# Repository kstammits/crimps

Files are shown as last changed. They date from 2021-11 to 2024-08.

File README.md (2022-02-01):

# crimps
 Mutated Kinks = Karltron Crimps

Originally cloning Mutable Instruments' Kinks
https://github.com/pichenettes/eurorack
Transferring from EAGLE to KiCad and updating from 0402 to 0805 construction means basically the whole thing is rewritten from scratch. The PCB is therefore unrelated to Kinks: Crimps is a karltron design 2021. 

Info on karltron.com/crimps

it's cc-by-sa so copyleft

On the internet forums, someone else has mentioned started a THT version, asking about it but not shared yet because reasons. 
https://modwiggler.com/forum/viewtopic.php?p=3644155

signal diode:
FDLL4148 is D1206

changing pinout on transistors, to SOT-23. so DO BE CAREFUL AND RECHECK THE PINOUT  (note v101 has the transistors on upside down, v122 is fixed)

layout looking fine in 0805

The S&H calls for a fancy C0G capacitor and OPA4171 opamp. We'll try it with a plain capacitor and TL074, which are compatible, but expect poor performance. I'm curious how poor, if it's acceptable we can save $$. Will try both, and report back here. But v101 is otherwise broken so 

when the input looks like noise at >9vpp, which is normal, the trigger goes off for successivly lower notes. feels like an accumulating towards -7.5Volts. Input values lower than -7V till self trigger If something softer is in the input, or values <7 volts absolute it will not self-trigger.  i think i need to add a capacitor somewhere or redo the ground plane.  Anytime the input sinks below -7V it pulls on the gate. Not sure it's really triggering, would need a two-channel scope to see if they coincide.  

if you keep the input above -7V, then the vgs doesn't trigger and everything is good. So I should just reduce the noise volume, the original kinks was showing just about +/-5V, and 10vpp is enough noise. mine's doing like 19vpp noise, and catching a very brief acquisition during noise spikes under -7V. 

so actually it works fine. i should/need/to/ reduce the noise volume to 10vpp to avoid the -7V issue. That's fixed by changing R27 from a 1.5M as originally given to a 1M. Now the noise is only +/-6V and everything works. then of course flip the transistors right-side-up. I've tested with only a J112 THT jfet tacked on crooked.  

Testing another JFET as replacement; the MMBFJ201 (marked 6P) is not great. Sort of works, sort of doesnt. The trigger time is not sufficient for acquisition, so each trigger can only move the sample by a few volts, and swinging +/-10V will need 2,3,4,5 triggers. Also, when the input is quite low the sample drains without triggers, so the J201 seems to have some leakage Igs as well as a higher Rds-on vs the J112. The incomplete-acquisitions problem might be okay for your use, but it really reduces the output range when the internal noise source is +/-6V and each trigger seems to only change the value to +/-1V. 

Testing the MMBF4392 (marked 6K)
Holds nicely down to -7.5V then drops, as others do, because my gate off voltage is -11, so less than four difference causes a sampling.   Seems to be working well. 

Testing the MMBFJ112 (marked 6R) last since a THT J112 was working well. Also seems to perform adequately. 
 
During hold testing, discovered unplugging and replugging the output causes a drop in the sample; perhaps this is caused by the brief short to ground pulling on the opamp. Additional decoupling caps did not help, looks like the OPA4171 final out buffer loses some state through the 180R output. Another output stage might be required to separate the held voltage from the output buffer. That's not fixable without additional chips.

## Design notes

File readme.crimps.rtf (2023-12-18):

Mutable Kinks
Karltron Crimps
21Nov08

it's cc-by-sa so copyleft
someone else started a tht version, asking about it but not shared yet because reasons.
on easyeda he doesnt know how to share that.

seems to fit in 0805 on one extra board. with no output LEDs.

FDLL4148 is D1206
i dont know if these diodes are pointing the right direction after changing footprints.
check the eagle schematic again for polarity.

21nov15

changing pinout on transistors, to SOT-23. so DO BE CAREFUL AND RECHECK THE PINOUT
checked. check.
layout looking fine in 0805. could do THT except for ICs.... well idk.
0805 is laid out now. needs review before ordering.
needs a https://www.digikey.com/en/products/detail/kemet/C0805C103J5GEC7210/8645966

the j112 seems to work well. but noise is dead.
give it an in and the s&h works. with J112 and OPA4174

FDLL pads could be taller please.
wrong jfet is fine. get a few to try.
upside down mmbf3904. needs rewrite of board.

seems the input normalled to noise is triggering the trigger perhaps by crosstalk. the falling tone is just the likelihood of a trigger getting seen.
after some exploration:
but its not crosstalk, i think its power rail fluctuations or ground plane shenanigans with the trigger's threshold, or trigger pulldown.
the original had a ton mroe decoupling, so that's a clue.

figured it out was just the gate threshold at -11 being too close to the input at -7v. we open the signal path
so really the module is fine lolol.
then changed the opa41 to a tl074 and found it pushes only -7v, so really triggery easier. the noise went up to +/-7 and that hits the gate easyyy.

v122 works great

update R27 down from 470K to maybe 330K or half 470 (parallel = 235K)

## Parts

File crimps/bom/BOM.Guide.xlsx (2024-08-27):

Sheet: BOM
Source: | /Users/karl/Workspace/KiCad/Crimps/crimps/k2.sch
Date: | Thursday, November 18, 2021 at 08:59:49 PM
Tool: | Eeschema (5.1.10-1-10_14)
Generator: | /private/var/folders/6g/062y2qc95n76y3fy2wkwz5l40000gn/T/AppTranslocation/AF1E8601-DF93-40C0-9ED7-950A2D177542/d/kicad.app/Contents/SharedSupport/plugins/bom_csv_grouped_by_value.py
Component Count: | 81
Individual Components:
Item | Qty | Reference(s) | Value | LibPart | Footprint | Datasheet
 |  | C1 | 22u | k2-eagle-import:C-USC0805 | Capacitor_THT:CP_Radial_D6.3mm_P2.50mm
 |  | C2 | 22u | k2-eagle-import:C-USC0805 | Capacitor_THT:CP_Radial_D6.3mm_P2.50mm
 |  | C3 | 100p | device:C | Capacitor_SMD:C_0805_2012Metric_Pad1.18x1.45mm_HandSolder
 |  | C4 | 100n | k2-eagle-import:C-USC0402 | Capacitor_SMD:C_0805_2012Metric_Pad1.18x1.45mm_HandSolder
 |  | C5 | 100n | k2-eagle-import:C-USC0402 | Capacitor_SMD:C_0805_2012Metric_Pad1.18x1.45mm_HandSolder
 |  | C6 | 100n | k2-eagle-import:C-USC0805 | Capacitor_SMD:C_0805_2012Metric_Pad1.18x1.45mm_HandSolder
 |  | C7 | 100n | k2-eagle-import:C-USC0805 | Capacitor_SMD:C_0805_2012Metric_Pad1.18x1.45mm_HandSolder
 |  | C8 | 100n | k2-eagle-import:C-USC0402 | Capacitor_SMD:C_0805_2012Metric_Pad1.18x1.45mm_HandSolder
 |  | C9 | 100n | k2-eagle-import:C-USC0402 | Capacitor_SMD:C_0805_2012Metric_Pad1.18x1.45mm_HandSolder
 |  | C10 | 4.7u | k2-eagle-import:C-USC0603 | Capacitor_SMD:C_0805_2012Metric_Pad1.18x1.45mm_HandSolder
 |  | C11 | 100n | device:C | Capacitor_SMD:C_0805_2012Metric_Pad1.18x1.45mm_HandSolder
 |  | C12 | 10n | device:C | Capacitor_SMD:C_0805_2012Metric_Pad1.18x1.45mm_HandSolder
 |  | D1 | S1JL | Device:D | Diode_THT:D_DO-41_SOD81_P10.16mm_Horizontal
 |  | D2 | S1JL | Device:D | Diode_THT:D_DO-41_SOD81_P10.16mm_Horizontal
 |  | D3 | 1N4148 | device:D | Diode_SMD:D_1206_3216Metric_Pad1.42x1.75mm_HandSolder
 |  | D4 | 1N4148 | device:D | Diode_SMD:D_1206_3216Metric_Pad1.42x1.75mm_HandSolder
 |  | D5 | 1N4148 | device:D | Diode_SMD:D_1206_3216Metric_Pad1.42x1.75mm_HandSolder
 |  | D6 | 1N4148 | device:D | Diode_SMD:D_1206_3216Metric_Pad1.42x1.75mm_HandSolder
 |  | D7 | 1N4148 | device:D | Diode_SMD:D_1206_3216Metric_Pad1.42x1.75mm_HandSolder
 |  | D8 | 1N4148 | device:D | Diode_SMD:D_1206_3216Metric_Pad1.42x1.75mm_HandSolder
 |  | D9 | 1N4148 | device:D | Diode_SMD:D_1206_3216Metric_Pad1.42x1.75mm_HandSolder
 |  | D10 | 1N4148 | device:D | Diode_SMD:D_1206_3216Metric_Pad1.42x1.75mm_HandSolder
 |  | D11 | 1N4148 | device:D | Diode_SMD:D_1206_3216Metric_Pad1.42x1.75mm_HandSolder
 |  | D12 | 1N4148 | device:D | Diode_SMD:D_1206_3216Metric_Pad1.42x1.75mm_HandSolder
 |  | IC1 | TL074 | Amplifier_Operational:TL074 | Package_SO:SOIC-14_3.9x8.7mm_P1.27mm
 |  | IC2 | TL072 | Amplifier_Operational:TL072 | Package_SO:SOIC-8_3.9x4.9mm_P1.27mm
 |  | IC3 | TL074 | Amplifier_Operational:TL074 | Package_SO:SOIC-14_3.9x8.7mm_P1.27mm
 |  | J1 | PJ301_THONKICONN6 | k2-eagle-import:PJ301_THONKICONN6 | k2:WQP_PJ_301M6
 |  | J2 | PJ301_THONKICONN6 | k2-eagle-import:PJ301_THONKICONN6 | k2:WQP_PJ_301M6
 |  | J3 | PJ301_THONKICONN6 | k2-eagle-import:PJ301_THONKICONN6 | k2:WQP_PJ_301M6
 |  | J4 | PJ301_THONKICONN6 | k2-eagle-import:PJ301_THONKICONN6 | k2:WQP_PJ_301M6
 |  | J5 | PJ301_THONKICONN6 | k2-eagle-import:PJ301_THONKICONN6 | k2:WQP_PJ_301M6
 |  | J6 | PJ301_THONKICONN6 | k2-eagle-import:PJ301_THONKICONN6 | k2:WQP_PJ_301M6
 |  | J7 | PJ301_THONKICONN6 | k2-eagle-import:PJ301_THONKICONN6 | k2:WQP_PJ_301M6
 |  | J8 | PJ301_THONKICONN6 | k2-eagle-import:PJ301_THONKICONN6 | k2:WQP_PJ_301M6
 |  | J9 | PJ301_THONKICONN6 | k2-eagle-import:PJ301_THONKICONN6 | k2:WQP_PJ_301M6
 |  | J10 | PJ301_THONKICONN6 | k2-eagle-import:PJ301_THONKICONN6 | k2:WQP_PJ_301M6
 |  | J11 | PJ301_THONKICONN6 | k2-eagle-import:PJ301_THONKICONN6 | k2:WQP_PJ_301M6
 |  | J12 | PJ301_THONKICONN6 | k2-eagle-import:PJ301_THONKICONN6 | k2:WQP_PJ_301M6
 |  | J13 | Conn_01x05_Female | Connector:Conn_01x05_Female | Connector_PinHeader_2.54mm:PinHeader_1x05_P2.54mm_Vertical | ~
 |  | J14 | Conn_01x05_Female | Connector:Conn_01x05_Female | Connector_PinHeader_2.54mm:PinHeader_1x05_P2.54mm_Vertical | ~
 |  | J15 | Conn_01x05_Female | Connector:Conn_01x05_Female | Connector_PinHeader_2.54mm:PinHeader_1x05_P2.54mm_Vertical | ~
 |  | J16 | Conn_01x05_Male | Connector:Conn_01x05_Male | Connector_PinHeader_2.54mm:PinHeader_1x05_P2.54mm_Vertical | ~
 |  | J17 | Conn_01x05_Male | Connector:Conn_01x05_Male | Connector_PinHeader_2.54mm:PinHeader_1x05_P2.54mm_Vertical | ~
 |  | J18 | Conn_01x05_Male | Connector:Conn_01x05_Male | Connector_PinHeader_2.54mm:PinHeader_1x05_P2.54mm_Vertical | ~
 |  | JP1 | M05X2PTH | k2-eagle-import:M05X2PTH | k2:AVR_ICSP
 |  | Q1 | MMBFJ309 | device:Q_NJFET_SDG | Package_TO_SOT_SMD:SOT-23_Handsoldering
 |  | Q2 | MMBT3904 | device:Q_NPN_EBC | Package_TO_SOT_SMD:SOT-23_Handsoldering
 |  | Q3 | MMBT3904 | device:Q_NPN_EBC | Package_TO_SOT_SMD:SOT-23_Handsoldering
 |  | R1 | 180 | k2-eagle-import:R-US_R0402 | Resistor_SMD:R_0805_2012Metric_Pad1.20x1.40mm_HandSolder
 |  | R2 | 180 | k2-eagle-import:R-US_R0402 | Resistor_SMD:R_0805_2012Metric_Pad1.20x1.40mm_HandSolder
 |  | R3 | 180 | k2-eagle-import:R-US_R0402 | Resistor_SMD:R_0805_2012Metric_Pad1.20x1.40mm_HandSolder
 |  | R4 | 180 | k2-eagle-import:R-US_R0402 | Resistor_SMD:R_0805_2012Metric_Pad1.20x1.40mm_HandSolder
 |  | R5 | 180 | k2-eagle-import:R-US_R0402 | Resistor_SMD:R_0805_2012Metric_Pad1.20x1.40mm_HandSolder
 |  | R6 | 180 | k2-eagle-import:R-US_R0402 | Resistor_SMD:R_0805_2012Metric_Pad1.20x1.40mm_HandSolder
 |  | R7 | 100k | k2-eagle-import:R-US_R0402 | Resistor_SMD:R_0805_2012Metric_Pad1.20x1.40mm_HandSolder
 |  | R8 | 180 | k2-eagle-import:R-US_R0402 | Resistor_SMD:R_0805_2012Metric_Pad1.20x1.40mm_HandSolder
 |  | R9 | 200k | k2-eagle-import:R-US_R0402 | Resistor_SMD:R_0805_2012Metric_Pad1.20x1.40mm_HandSolder
 |  | R10 | 200k | k2-eagle-import:R-US_R0402 | Resistor_SMD:R_0805_2012Metric_Pad1.20x1.40mm_HandSolder
 |  | R11 | 200k | k2-eagle-import:R-US_R0402 | Resistor_SMD:R_0805_2012Metric_Pad1.20x1.40mm_HandSolder
 |  | R12 | 200k | k2-eagle-import:R-US_R0402 | Resistor_SMD:R_0805_2012Metric_Pad1.20x1.40mm_HandSolder
 |  | R13 | 200k | k2-eagle-import:R-US_R0402 | Resistor_SMD:R_0805_2012Metric_Pad1.20x1.40mm_HandSolder
 |  | R14 | 100k | k2-eagle-import:R-US_R0402 | Resistor_SMD:R_0805_2012Metric_Pad1.20x1.40mm_HandSolder
 |  | R15 | 200k | k2-eagle-import:R-US_R0402 | Resistor_SMD:R_0805_2012Metric_Pad1.20x1.40mm_HandSolder
 |  | R16 | 100k | k2-eagle-import:R-US_R0402 | Resistor_SMD:R_0805_2012Metric_Pad1.20x1.40mm_HandSolder
 |  | R17 | 100k | k2-eagle-import:R-US_R0402 | Resistor_SMD:R_0805_2012Metric_Pad1.20x1.40mm_HandSolder
 |  | R18 | 100k | k2-eagle-import:R-US_R0402 | Resistor_SMD:R_0805_2012Metric_Pad1.20x1.40mm_HandSolder
 |  | R19 | 220k | k2-eagle-import:R-US_R0402 | Resistor_SMD:R_0805_2012Metric_Pad1.20x1.40mm_HandSolder
 |  | R20 | 220k | k2-eagle-import:R-US_R0402 | Resistor_SMD:R_0805_2012Metric_Pad1.20x1.40mm_HandSolder
 |  | R21 | 220k | k2-eagle-import:R-US_R0402 | Resistor_SMD:R_0805_2012Metric_Pad1.20x1.40mm_HandSolder
 |  | R22 | 220k | k2-eagle-import:R-US_R0402 | Resistor_SMD:R_0805_2012Metric_Pad1.20x1.40mm_HandSolder
 |  | R23 | 10k | k2-eagle-import:R-US_R0402 | Resistor_SMD:R_0805_2012Metric_Pad1.20x1.40mm_HandSolder
 |  | R24 | 1.0M | k2-eagle-import:R-US_R0402 | Resistor_SMD:R_0805_2012Metric_Pad1.20x1.40mm_HandSolder
 |  | R25 | 10k | k2-eagle-import:R-US_R0402 | Resistor_SMD:R_0805_2012Metric_Pad1.20x1.40mm_HandSolder
 |  | R26 | 1.0M | k2-eagle-import:R-US_R0402 | Resistor_SMD:R_0805_2012Metric_Pad1.20x1.40mm_HandSolder
 |  | R27 | 1.5M | k2-eagle-import:R-US_R0402 | Resistor_SMD:R_0805_2012Metric_Pad1.20x1.40mm_HandSolder
 |  | R28 | 100k | k2-eagle-import:R-US_R0402 | Resistor_SMD:R_0805_2012Metric_Pad1.20x1.40mm_HandSolder
 |  | R29 | 1.0M | k2-eagle-import:R-US_R0402 | Resistor_SMD:R_0805_2012Metric_Pad1.20x1.40mm_HandSolder
 |  | R30 | 470k | k2-eagle-import:R-US_R0402 | Resistor_SMD:R_0805_2012Metric_Pad1.20x1.40mm_HandSolder
 |  | R31 | 4.7k | k2-eagle-import:R-US_R0402 | Resistor_SMD:R_0805_2012Metric_Pad1.20x1.40mm_HandSolder
 |  | R32 | 100k | k2-eagle-import:R-US_R0402 | Resistor_SMD:R_0805_2012Metric_Pad1.20x1.40mm_HandSolder
Collated Components:
Item | Qty | Reference(s) | Value | LibPart | Footprint | Datasheet
1 | 2 | C1, C2 | 22u | k2-eagle-import:C-USC0805 | Capacitor_THT:CP_Radial_D6.3mm_P2.50mm
2 | 1 | C3 | 100p | device:C | Capacitor_SMD:C_0805_2012Metric_Pad1.18x1.45mm_HandSolder
3 | 4 | C4, C5, C8, C9 | 100n | k2-eagle-import:C-USC0402 | Capacitor_SMD:C_0805_2012Metric_Pad1.18x1.45mm_HandSolder
4 | 2 | C6, C7 | 100n | k2-eagle-import:C-USC0805 | Capacitor_SMD:C_0805_2012Metric_Pad1.18x1.45mm_HandSolder
5 | 1 | C10 | 4.7u | k2-eagle-import:C-USC0603 | Capacitor_SMD:C_0805_2012Metric_Pad1.18x1.45mm_HandSolder
6 | 1 | C11 | 100n | device:C | Capacitor_SMD:C_0805_2012Metric_Pad1.18x1.45mm_HandSolder
7 | 1 | C12 | 10n | device:C | Capacitor_SMD:C_0805_2012Metric_Pad1.18x1.45mm_HandSolder
8 | 2 | D1, D2 | S1JL | Device:D | Diode_THT:D_DO-41_SOD81_P10.16mm_Horizontal
9 | 10 | D3, D4, D5, D6, D7, D8, D9, D10, D11, D12 | 1N4148 | device:D | Diode_SMD:D_1206_3216Metric_Pad1.42x1.75mm_HandSolder
10 | 2 | IC1, IC3 | TL074 | Amplifier_Operational:TL074 | Package_SO:SOIC-14_3.9x8.7mm_P1.27mm
11 | 1 | IC2 | TL072 | Amplifier_Operational:TL072 | Package_SO:SOIC-8_3.9x4.9mm_P1.27mm
12 | 12 | J1, J2, J3, J4, J5, J6, J7, J8, J9, J10, J11, J12 | PJ301_THONKICONN6 | k2-eagle-import:PJ301_THONKICONN6 | k2:WQP_PJ_301M6
13 | 3 | J13, J14, J15 | Conn_01x05_Female | Connector:Conn_01x05_Female | Connector_PinHeader_2.54mm:PinHeader_1x05_P2.54mm_Vertical | ~
14 | 3 | J16, J17, J18 | Conn_01x05_Male | Connector:Conn_01x05_Male | Connector_PinHeader_2.54mm:PinHeader_1x05_P2.54mm_Vertical | ~
15 | 1 | JP1 | M05X2PTH | k2-eagle-import:M05X2PTH | k2:AVR_ICSP
16 | 1 | Q1 | MMBFJ309 | device:Q_NJFET_SDG | Package_TO_SOT_SMD:SOT-23_Handsoldering
17 | 2 | Q2, Q3 | MMBT3904 | device:Q_NPN_EBC | Package_TO_SOT_SMD:SOT-23_Handsoldering
18 | 7 | R1, R2, R3, R4, R5, R6, R8 | 180 | k2-eagle-import:R-US_R0402 | Resistor_SMD:R_0805_2012Metric_Pad1.20x1.40mm_HandSolder
19 | 7 | R7, R14, R16, R17, R18, R28, R32 | 100k | k2-eagle-import:R-US_R0402 | Resistor_SMD:R_0805_2012Metric_Pad1.20x1.40mm_HandSolder
20 | 6 | R9, R10, R11, R12, R13, R15 | 200k | k2-eagle-import:R-US_R0402 | Resistor_SMD:R_0805_2012Metric_Pad1.20x1.40mm_HandSolder
21 | 4 | R19, R20, R21, R22 | 220k | k2-eagle-import:R-US_R0402 | Resistor_SMD:R_0805_2012Metric_Pad1.20x1.40mm_HandSolder
22 | 2 | R23, R25 | 10k | k2-eagle-import:R-US_R0402 | Resistor_SMD:R_0805_2012Metric_Pad1.20x1.40mm_HandSolder
23 | 3 | R24, R26, R29 | 1.0M | k2-eagle-import:R-US_R0402 | Resistor_SMD:R_0805_2012Metric_Pad1.20x1.40mm_HandSolder
24 | 1 | R27 | 1.5M | k2-eagle-import:R-US_R0402 | Resistor_SMD:R_0805_2012Metric_Pad1.20x1.40mm_HandSolder
25 | 1 | R30 | 470k | k2-eagle-import:R-US_R0402 | Resistor_SMD:R_0805_2012Metric_Pad1.20x1.40mm_HandSolder
26 | 1 | R31 | 4.7k | k2-eagle-import:R-US_R0402 | Resistor_SMD:R_0805_2012Metric_Pad1.20x1.40mm_HandSolder

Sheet: GUIDE
Crimps v122 karltron.com December 2021 - Derived from Mutable Kinks v4.1 cc-by-sa
Step | Qty | Reference(s) | Value | Footprint | Note
1 | 7 | R1, R2, R3, R4, R5, R6, R8 | 180R | 0805 plain | output protections, could be 100R to 1K
2 | 7 | R7, R14, R16, R17, R18, R28, R32 | 100k | 0805 plain
3 | 6 | R9, R10, R11, R12, R13, R15 | 200k | 0805 plain
4 | 4 | R19, R20, R21, R22 | 220k | 0805 plain
5 | 2 | R23, R25 | 10k | 0805 plain
6 | 3 | R24, R26, R29 | 1.0M | 0805 plain
7 | 2 | R27, R30 | 470k | 0805 plain | R27 sets noise volume
8 | 1 | R31 | 4.7k | 0805 plain
9 | 1 | C3 | 100p | 0805 plain | trigger conditioning
10 | 7 | C4, C5, C6, C7, C8, C9,C11 | 100n | 0805 plain
11 | 1 | C10 | 4.7u | 0805 plain | buffer before noise generator, value not critical
12 | 1 | C12 | 10n | 0805 C0G special | sample/hold
13 | 10 | D3, D4, D5, D6, D7, D8, D9, D10, D11, D12 | 1N4148 or FDLL4148 | Diode_SMD:D_1206_3216Metric_Pad1.42x1.75mm_HandSolder | FDLL4148 or generic signal diode
14 | 1 | IC3 | OPA4171 | SOIC-14_3.9x8.7mm_P1.27mm | a tl074 almost works but the fancy opamp is better
15 | 1 | IC1 | TL074 | SOIC-14_3.9x8.7mm_P1.27mm
16 | 1 | IC2 | TL072 | SOIC-8_3.9x4.9mm_P1.27mm
17 | 1 | Q1 | MMBFJ309 | SOT-23 | J112 and MMBF4392 work too
18 | 2 | Q2, Q3 | MMBT3904 | SOT-23 | NPN Plain
19 | 1 | JP1 | M05X2PTH | power connector 2x5 | shrouded fits
20 | 2 | C1, C2 | 22u | Cap_THT:D6.3mm_P2.50mm | pre-bend to lay flat on board inside
21 | 2 | D1, D2 | 1N4001 or 1N5819 | Diode_THT:D_DO-41_SOD81 | reverse power protection optional, could jumper these with wire instead of series diode drop
22 | 3 | J13, J14, J15 | Conn_01x05_Female | Connector_PinHeader_2.54mm:PinHeader_1x05_P2.54mm_Vertical
23 | 3 | J16, J17, J18 | Conn_01x05_Male | Connector_PinHeader_2.54mm:PinHeader_1x05_P2.54mm_Vertical
24 | 12 | J1, J2, J3, J4, J5, J6, J7, J8, J9, J10, J11, J12 | PJ301 THONKICONN | Switching Mono-Jack

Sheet: Costing
Step | Qty | Reference(s) | Value | Footprint | Note | Shopping | Cost Estimate | Extended
1 | 7 | R1, R2, R3, R4, R5, R6, R8 | 180R | 0805 plain |  | incoming Mouser | $0.01 | $0.07
2 | 7 | R7, R14, R16, R17, R18, R28, R32 | 100k | 0805 plain |  |  | $0.01 | $0.07 | Packing/Picking | PCB Set | Total Kit Price estimate
3 | 6 | R9, R10, R11, R12, R13, R15 | 200k | 0805 plain |  | incoming Mouser | $0.01 | $0.06 | $30.00 | $20.00 | $67.67
4 | 4 | R19, R20, R21, R22 | 220k | 0805 plain |  |  | $0.01 | $0.04
5 | 2 | R23, R25 | 10k | 0805 plain |  |  | $0.01 | $0.02
6 | 3 | R24, R26, R29 | 1.0M | 0805 plain |  |  | $0.01 | $0.03
7 | 1 | R27 | 1.5M | 0805 plain | change to 1M |  | $0.01 | $0.01
8 | 1 | R30 | 470k | 0805 plain |  |  | $0.01 | $0.01
9 | 1 | R31 | 4.7k | 0805 plain |  |  | $0.01 | $0.01
10 | 1 | C3 | 100p | 0805 plain |  | incoming Mouser | $0.04 | $0.04
11 | 6 | C4, C5, C6, C7, C8, C9,C11 | 100n | 0805 plain |  |  | $0.02 | $0.12
12 | 1 | C10 | 4.7u | 0805 plain | buffer before noise generator, value not critical |  | $0.10 | $0.10
13 | 1 | C12 | 10n | 0805 C0G special | sample/hold | incoming Mouser | $0.15 | $0.15
14 | 10 | D3, D4, D5, D6, D7, D8, D9, D10, D11, D12 | 1N4148 or FDLL4148 | Diode_SMD:D_1206_3216Metric_Pad1.42x1.75mm_HandSolder | FDLL4148 or generic signal diode |  | $0.04 | $0.40
15 | 1 | IC3 | OPA4147 or maybe TL074 IDK | Package_SO:SOIC-14_3.9x8.7mm_P1.27mm |  | incoming Mouser | $3.00 | $3.00
16 | 1 | IC1 | TL074 | Package_SO:SOIC-14_3.9x8.7mm_P1.27mm |  |  | $0.50 | $0.50
17 | 1 | IC2 | TL072 | Package_SO:SOIC-8_3.9x4.9mm_P1.27mm |  |  | $0.50 | $0.50
18 | 1 | Q1 | MMBFJ309 | SOT-23 | jfet | incoming eBay 2022 | $0.30 | $0.30
19 | 2 | Q2, Q3 | MMBT3904 | SOT-23 | NPN Plain |  | $0.10 | $0.20
20 | 2 | C1, C2 | 22u | Capacitor_THT:CP_Radial_D6.3mm_P2.50mm |  |  | $0.30 | $0.60
21 | 2 | D1, D2 | 1N4001 or 1N5819 | Diode_THT:D_DO-41_SOD81 | reverse power protection optional, could jumper these with wire instead of series diode drop |  | $0.20 | $0.40
22 | 3 | J13, J14, J15 | Conn_01x05_Female | Connector_PinHeader_2.54mm:PinHeader_1x05_P2.54mm_Vertical |  |  | $0.15 | $0.45
23 | 3 | J16, J17, J18 | Conn_01x05_Male | Connector_PinHeader_2.54mm:PinHeader_1x05_P2.54mm_Vertical |  |  | $0.15 | $0.45
24 | 1 | JP1 | M05X2PTH | power connector 2x5 | shrouded should fit |  | $0.25 | $0.25
25 | 12 | J1, J2, J3, J4, J5, J6, J7, J8, J9, J10, J11, J12 | PJ301_THONKICONN6 | Switching Mono-Jack |  |  | $0.25 | $3.00
 | 1 | power cable |  |  |  |  | $1.00 | $1.00
 |  | PCBs

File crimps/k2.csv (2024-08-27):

Source: | /Users/karl/Workspace/KiCad/Crimps/crimps/k2.kicad_sch
Date: | 2024 August 26, Monday 20:46:26
Tool: | Eeschema 7.0.2-0
Generator: | /Applications/KiCad/KiCad.app/Contents/SharedSupport/plugins/bom_csv_grouped_by_value_with_fp.py
Component Count: | 81
Ref | Qnty | Value | Cmp name | Footprint | Description | Vendor | DNP
C1, C2 | 2 | 22u | C-USC0805 | Capacitor_THT:CP_Radial_D6.3mm_P2.50mm
C3 | 1 | 100p | C-device | Capacitor_SMD:C_0805_2012Metric_Pad1.18x1.45mm_HandSolder
C4, C5, C6, C7, C8, C9, C11 | 7 | 100n | C-device | Capacitor_SMD:C_0805_2012Metric_Pad1.18x1.45mm_HandSolder
C10 | 1 | 4.7u | C-USC0603 | Capacitor_SMD:C_0805_2012Metric_Pad1.18x1.45mm_HandSolder
C12 | 1 | 10n | C-device | Capacitor_SMD:C_0805_2012Metric_Pad1.18x1.45mm_HandSolder
D1, D2 | 2 | S1JL | D | Diode_THT:D_DO-41_SOD81_P10.16mm_Horizontal | Diode
D3, D4, D5, D6, D7, D8, D9, D10, D11, D12 | 10 | 1N4148 | D-device | Diode_SMD:D_1206_3216Metric_Pad1.42x1.75mm_HandSolder
IC1 | 1 | TL074 | TL074 | Package_SO:SOIC-14_3.9x8.7mm_P1.27mm | Quad Low-Noise JFET-Input Operational Amplifiers, DIP-14/SOIC-14
IC2 | 1 | TL072 | TL072 | Package_SO:SOIC-8_3.9x4.9mm_P1.27mm | Dual Low-Noise JFET-Input Operational Amplifiers, DIP-8/SOIC-8
IC3 | 1 | OPA4171 | TL074 | Package_SO:SOIC-14_3.9x8.7mm_P1.27mm | Quad Low-Noise JFET-Input Operational Amplifiers, DIP-14/SOIC-14
J1, J2, J3, J4, J5, J6, J7, J8, J9, J10, J11, J12 | 12 | PJ301_THONKICONN6 | PJ301_THONKICONN6 | k2:WQP_PJ_301M6
J13, J14, J15 | 3 | Conn_01x05_Female | Conn_01x05_Female-Connector | Connector_PinHeader_2.54mm:PinHeader_1x05_P2.54mm_Vertical
J16, J17, J18 | 3 | Conn_01x05_Male | Conn_01x05_Male-Connector | Connector_PinHeader_2.54mm:PinHeader_1x05_P2.54mm_Vertical
JP1 | 1 | M05X2PTH | M05X2PTH | k2:AVR_ICSP
Q1 | 1 | MMBFJ309 | Q_NJFET_SDG-device | Package_TO_SOT_SMD:SOT-23_Handsoldering
Q2, Q3 | 2 | MMBT3904 | Q_NPN_BEC-device | Package_TO_SOT_SMD:SOT-23_Handsoldering
R1, R2, R3, R4, R5, R6, R8 | 7 | 180 | R-US_R0402 | Resistor_SMD:R_0805_2012Metric_Pad1.20x1.40mm_HandSolder
R7, R14, R16, R17, R18, R28, R32 | 7 | 100k | R-US_R0402 | Resistor_SMD:R_0805_2012Metric_Pad1.20x1.40mm_HandSolder
R9, R10, R11, R12, R13, R15 | 6 | 200k | R-US_R0402 | Resistor_SMD:R_0805_2012Metric_Pad1.20x1.40mm_HandSolder
R19, R20, R21, R22 | 4 | 220k | R-US_R0402 | Resistor_SMD:R_0805_2012Metric_Pad1.20x1.40mm_HandSolder
R23, R25 | 2 | 10k | R-US_R0402 | Resistor_SMD:R_0805_2012Metric_Pad1.20x1.40mm_HandSolder
R24, R26, R29 | 3 | 1.0M | R-US_R0402 | Resistor_SMD:R_0805_2012Metric_Pad1.20x1.40mm_HandSolder
R27 | 1 | 470K | R-US_R0402 | Resistor_SMD:R_0805_2012Metric_Pad1.20x1.40mm_HandSolder
R30 | 1 | 470k | R-US_R0402 | Resistor_SMD:R_0805_2012Metric_Pad1.20x1.40mm_HandSolder
R31 | 1 | 4.7k | R-US_R0402 | Resistor_SMD:R_0805_2012Metric_Pad1.20x1.40mm_HandSolder

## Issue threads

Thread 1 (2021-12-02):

Report back on using plain capacitors and TL074

drChungus, 2021-12-02:
Heyy,

Believe it or not, I am also considering building the Kinks nowadays and had the same idea to exchange the opamp to a more generic (and currently available) alternative. I was just wondering if you could go ahead with the build with the TL074 and if it really did make a difference in the S&H performance?

Thanks!

kstammits, 2021-12-13:
I'm having other issues on this version of the board. Will test out opamps after the rest of it is working.   For sure we don't need tantalums, i'm using MLCC and it seems okay. Kept with the C0G on the hold cap, and have so far the wrong JFET.  Today's board layout has some crosstalk problem where input noise can trigger the sampling, so that's broken. needs a re-route.

kstammits, 2021-12-17:
The strange self-triggering behavior, as it turns out, is the nature of a JFET based analog S&H. The voltage between gate and source needs to be better than 3 or 4 volts to ensure it is not sampling. Initially my noise source, normalled to input, was running +/-9V and whenever it hit -7V it would initiate a sample. This is solved in the original Kinks by changing the noise source to only +/-5V. Same here, I'm adjusting R27 to 1M so we have noise at +/-6V and no more self-triggers.

 This is relevant to the opamp choice question because the TL074 cannot output within 3-4 volts of its negative rail.  therefore the trigger/not trigger state is about -7V, and your JFET will sample whenever the input gets to about -3V, which is all the darn time with good noise input.

You can workaround this problem by further reducing the internal noise source at R27 to maybe 330K, but I think that really hobbles the utility.  In this instance we want a better than average opamp so that it can well encompass the plain opamps the rest of your system is feeding it.  If your input is a not rail-to-rail opamp then it never reaches this problematic region. Maybe also good in 15V systems.

Have not tested cheaper holding capacitors, expect it to reduce the hold time (increase droop), and I don't know what hold time is acceptable for all users, so there's no harm keeping with the special ones at fifteen cents each.    https://www.mouser.com/ProductDetail/810-CGA4C2C0G1H103J

KeLaiFu, 2021-12-18:
sorry its a little vague, but I saw another version of this posted a few days ago that mentioned some additional tuning was needed for the S&H circuit. I think my tuning they meant carefully matching components.

kstammits, 2021-12-29:
The key issue with the opamp seems to be the rail-to-rail nature. the sampling/hold action triggers whenever the trigger/gate goes high. The JFET calls high anything not more than 3 or 4 volts below the inputs. You could maybe find a special JFET who thinks that threshold is 2 volts or 5 volts. But in any event, when the trigger is not being triggered, the opamp is buffering it as low as it can go. For a TL074 that might be only -8 volts, so your S&H will take a sample whenever the input gets to -4V; and with a +/-5V noise normalled to in, that's all the time, and the module is useless.  So you could tune the normal noise to just +/-2V, or use a rail-to-rail opamp, so it can reproduce -11V and withstand a -5V at the input.

In conclusion, the originally specced OPA**** works better than a cheaper opamp.

Closed 2021-12-29.

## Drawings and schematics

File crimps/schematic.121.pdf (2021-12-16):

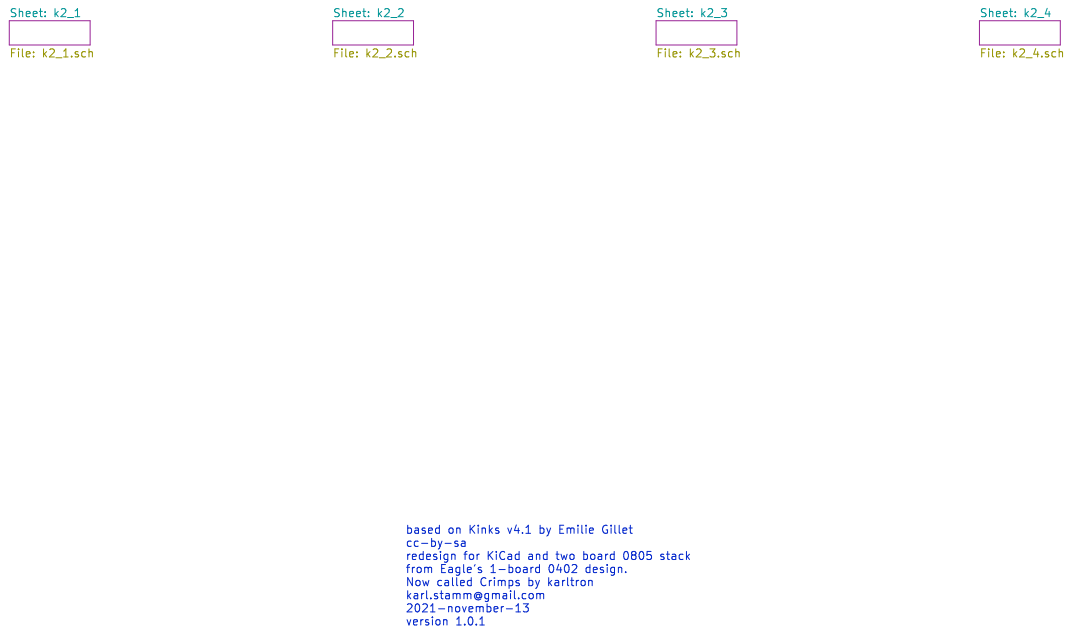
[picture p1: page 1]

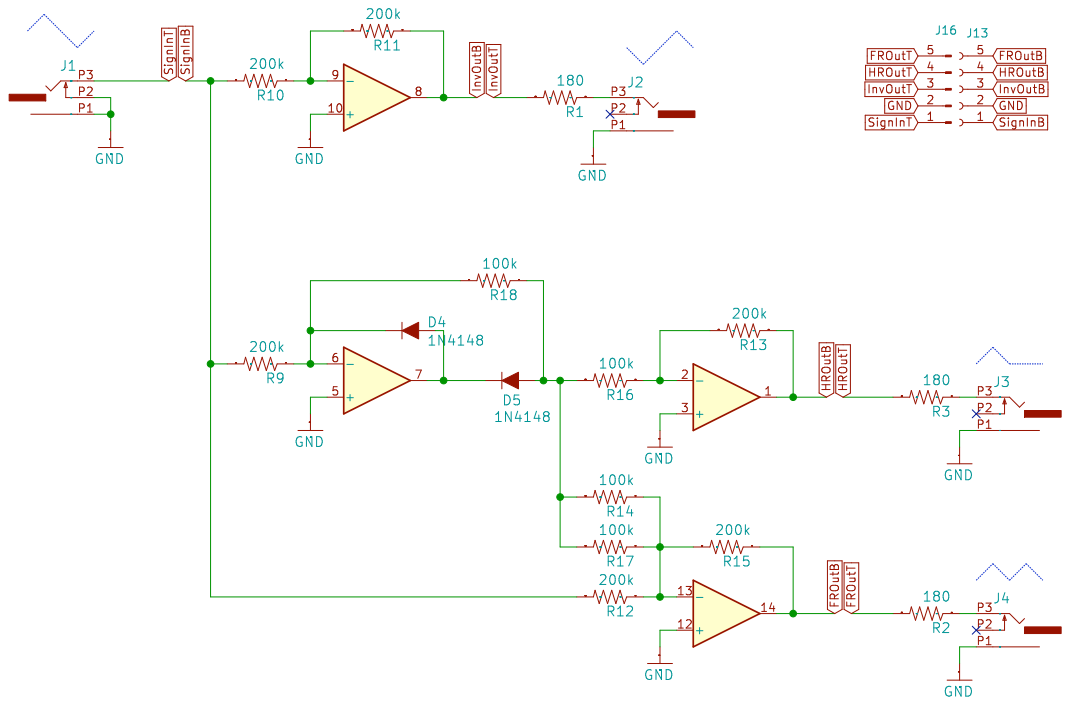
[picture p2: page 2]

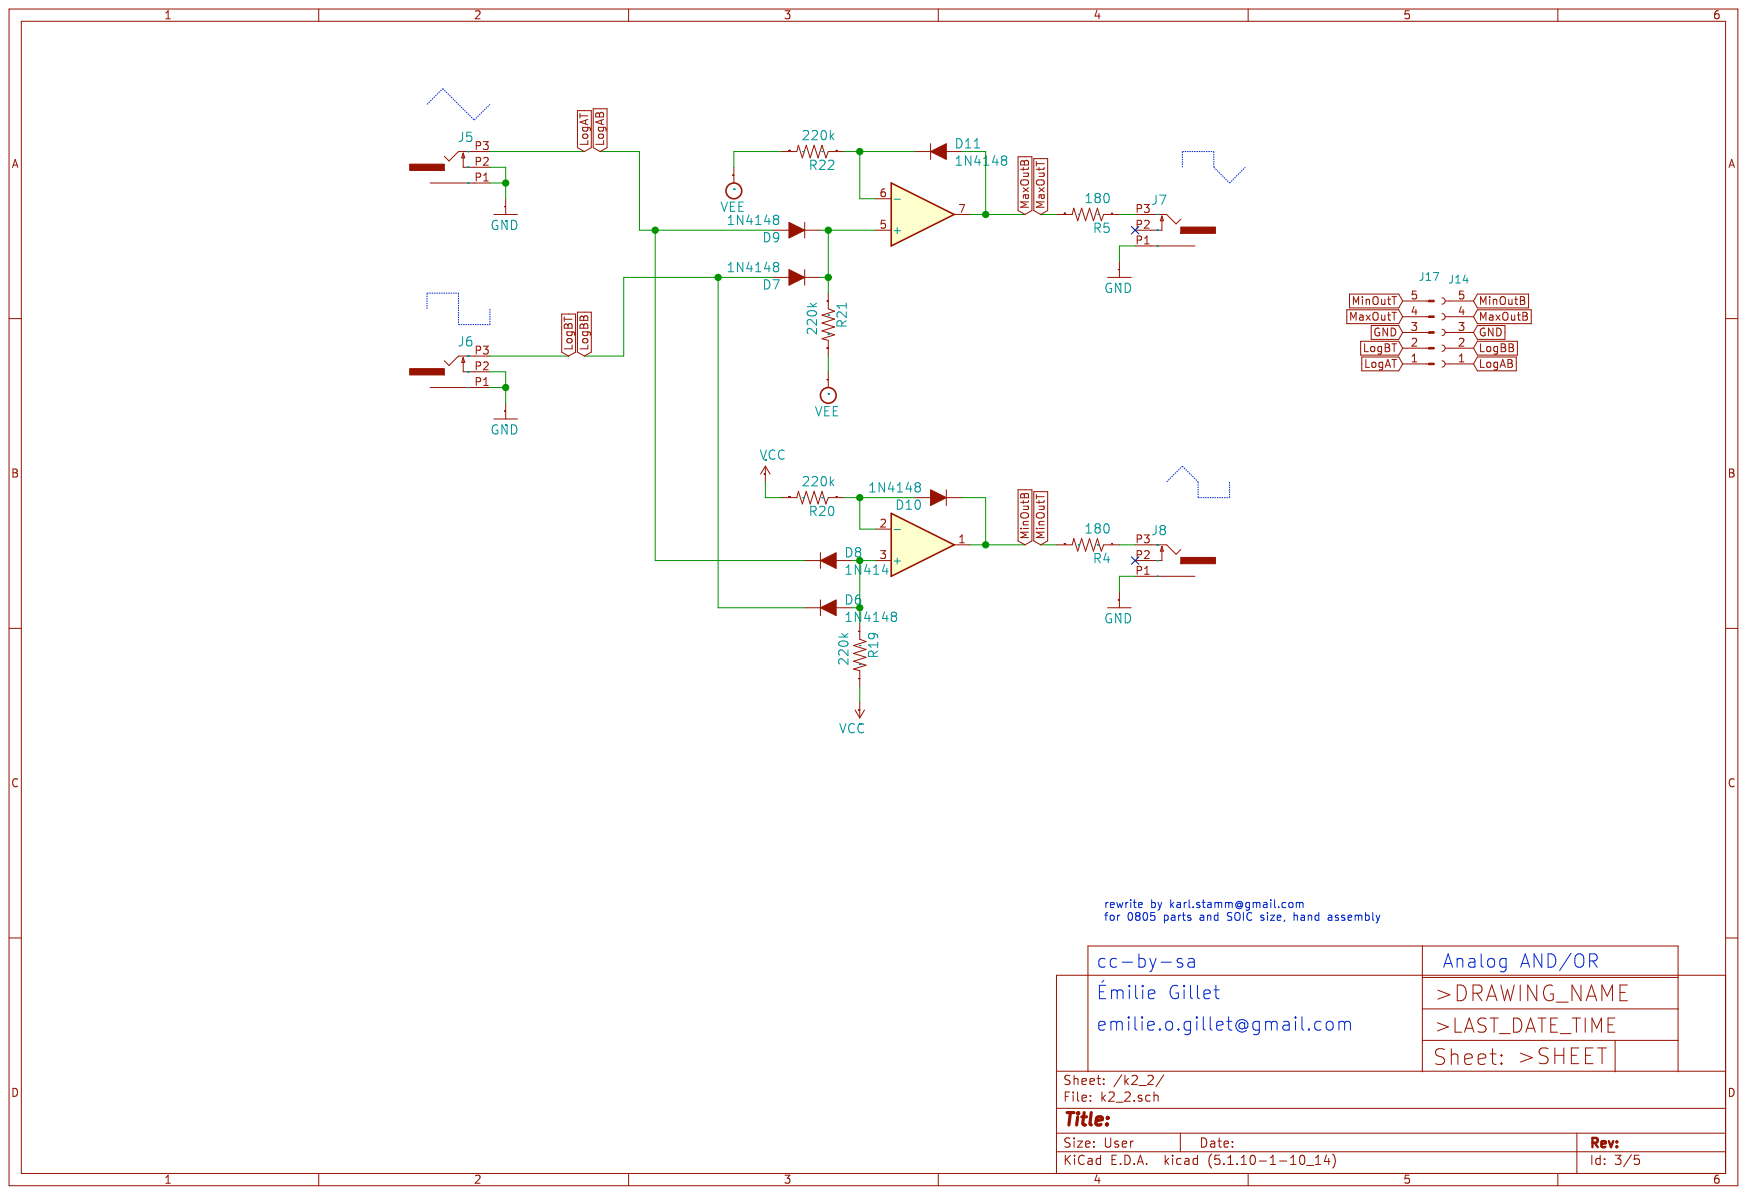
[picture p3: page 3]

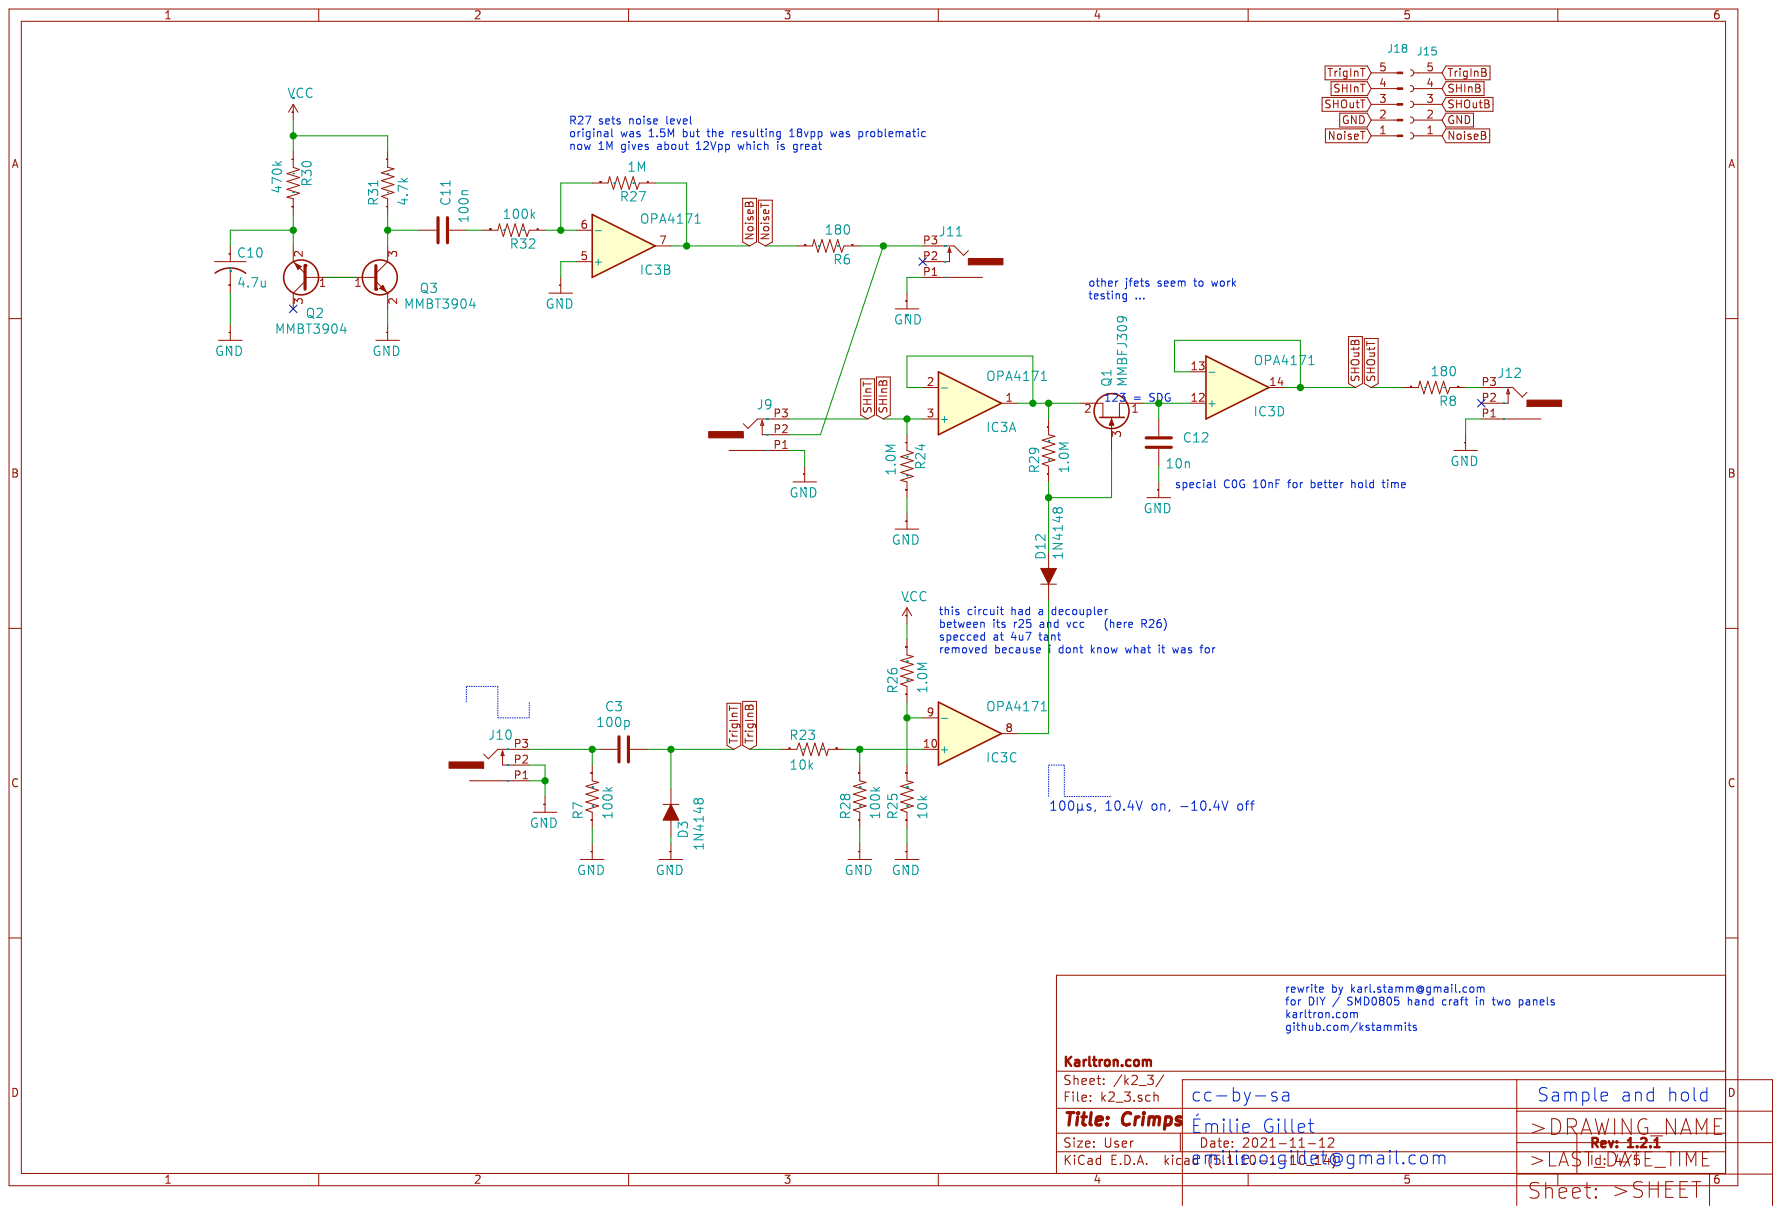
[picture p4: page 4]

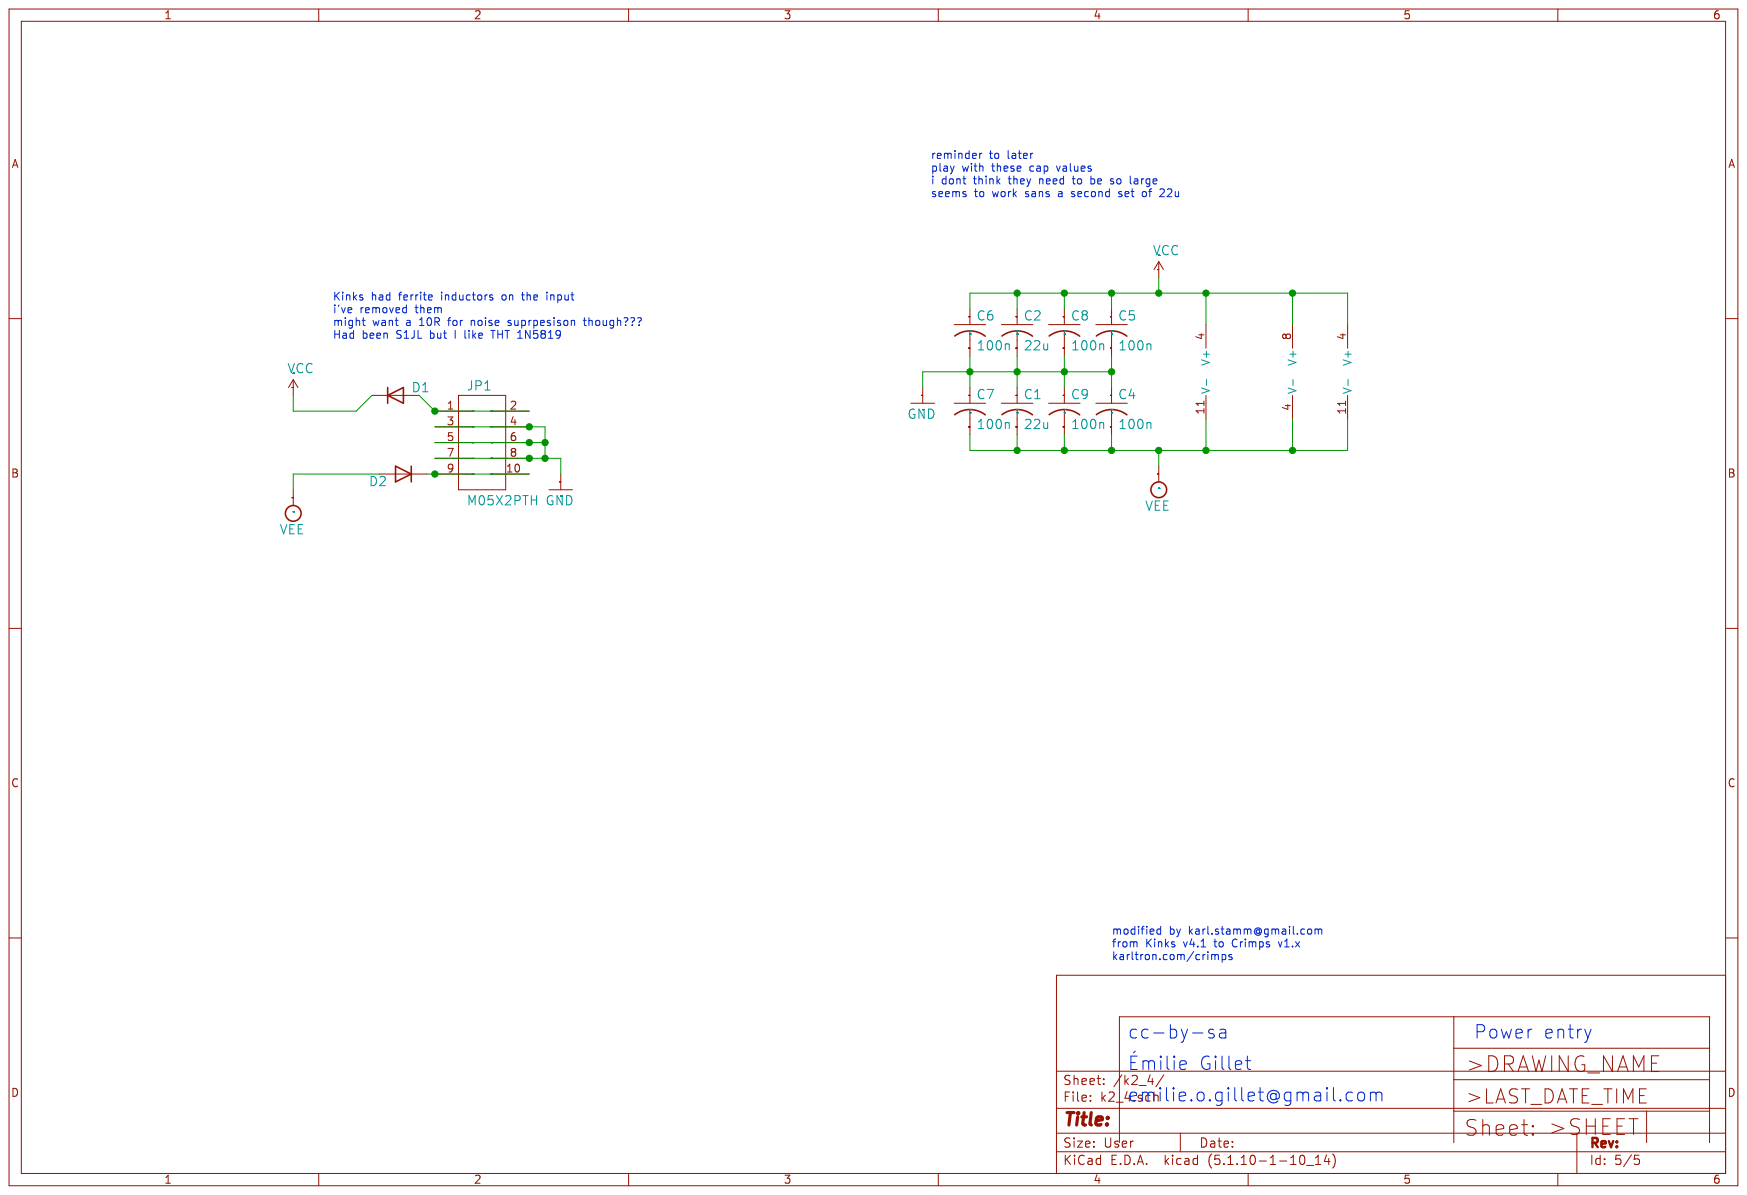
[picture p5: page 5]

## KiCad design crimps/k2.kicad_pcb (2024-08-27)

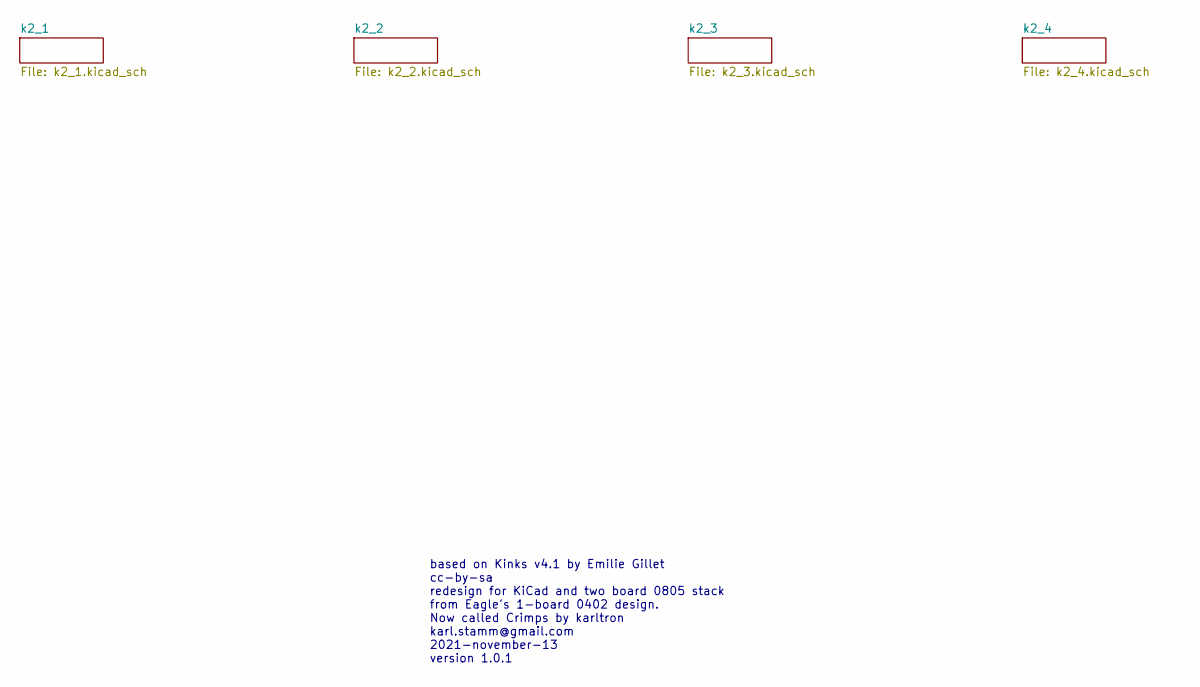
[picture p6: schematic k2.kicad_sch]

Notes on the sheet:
based on Kinks v4.1 by Emilie Gillet cc-by-sa redesign for KiCad and two board 0805 stack from Eagle's 1-board 0402 design. Now called Crimps by karltron karl.stamm@gmail.com 2021-november-13 version 1.0.1

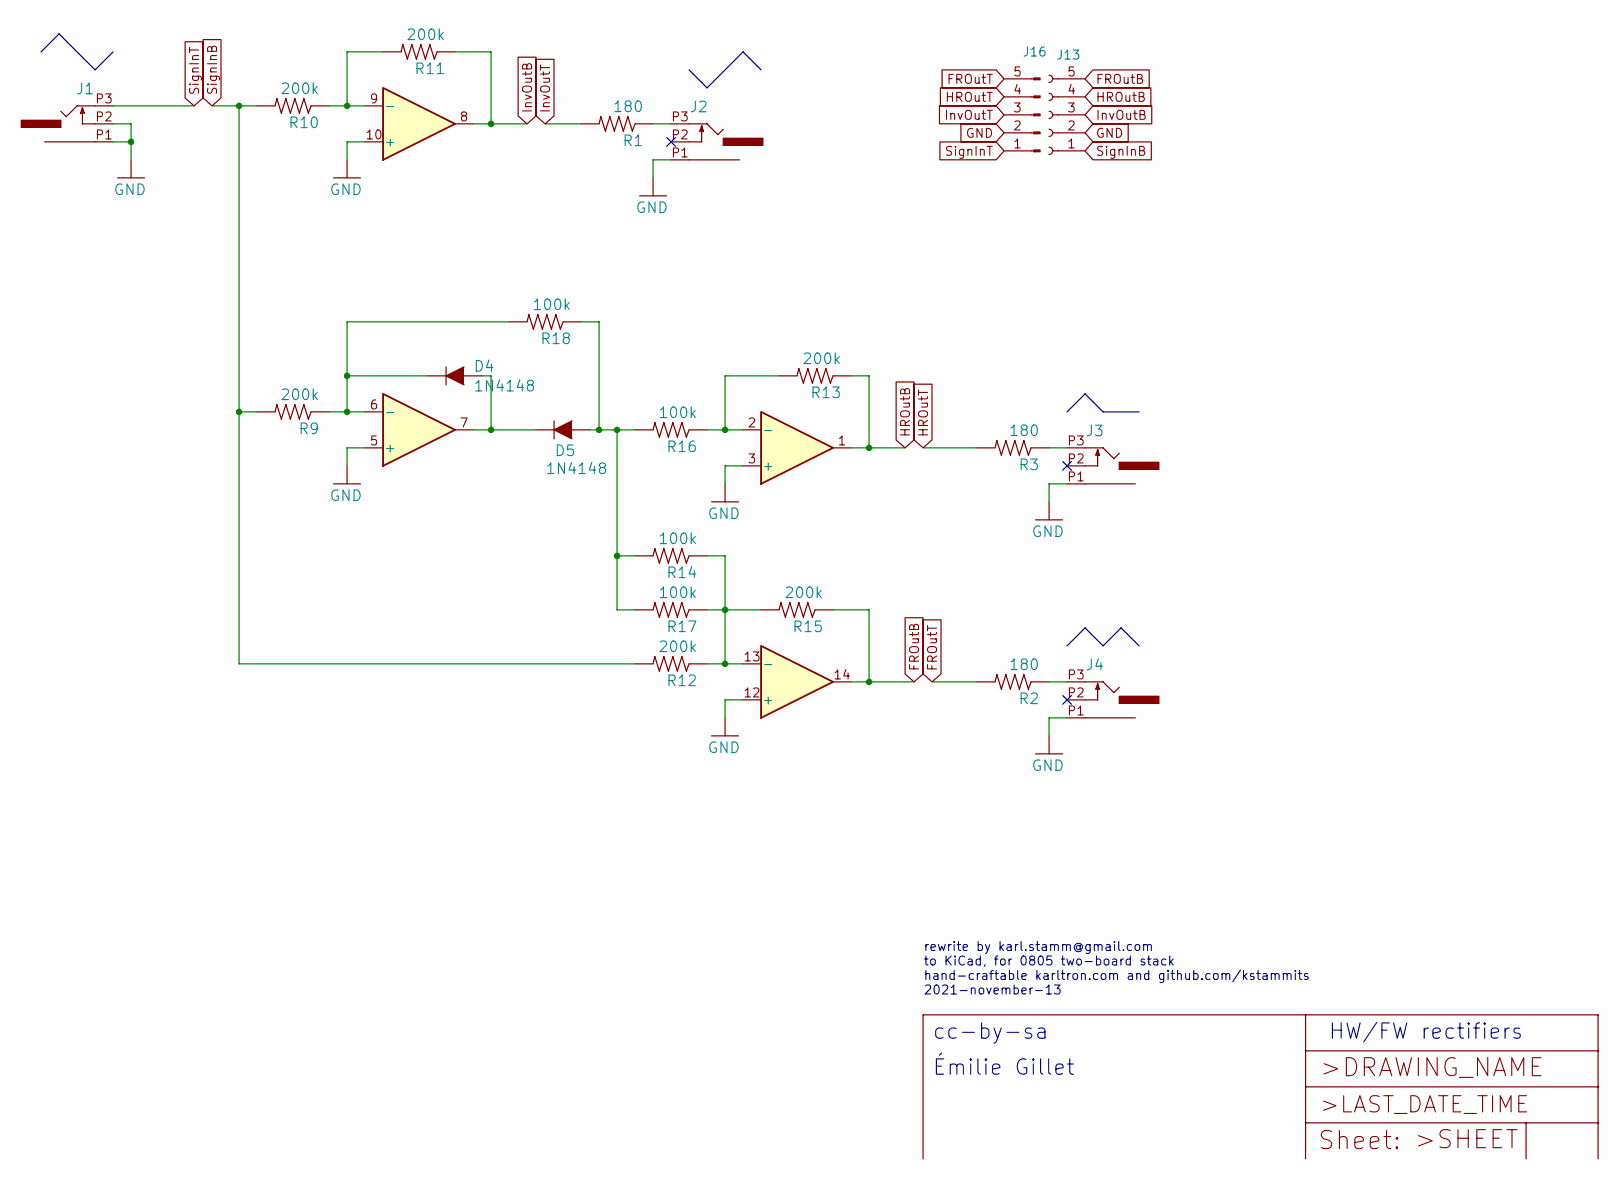
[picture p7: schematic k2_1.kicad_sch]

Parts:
D4, D5: 1N4148; D_1206_3216Metric_Pad1.42x1.75mm_HandSolder
IC1: TL074; SOIC-14_3.9x8.7mm_P1.27mm
J1, J2, J3, J4: PJ301_THONKICONN6; WQP_PJ_301M6
J13: Conn_01x05_Female; PinHeader_1x05_P2.54mm_Vertical
J16: Conn_01x05_Male; PinHeader_1x05_P2.54mm_Vertical
R1, R2, R3: 180; R_0805_2012Metric_Pad1.20x1.40mm_HandSolder
R9, R10, R11, R12, R13, R15: 200k; R_0805_2012Metric_Pad1.20x1.40mm_HandSolder
R14, R16, R17, R18: 100k; R_0805_2012Metric_Pad1.20x1.40mm_HandSolder

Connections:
FROutB: IC1.14, J13.5, R15.1
FROutT: J16.5, R2.2
GND: IC1.3 (+), IC1.5 (+), IC1.10 (+), IC1.12 (+), J1.P1 (1), J1.P2 (2), J2.P1 (1), J3.P1 (1), J4.P1 (1), J13.2, J16.2; also elsewhere on the board
HROutB: IC1.1, J13.4, R13.1
HROutT: J16.4, R3.2
InvOutB: IC1.8, J13.3, R11.1
InvOutT: J16.3, R1.2
unnamed: D4.2 (A), D5.1 (K), IC1.7
unnamed: D4.1 (K), IC1.6 (-), R9.1, R18.2
unnamed: D5.2 (A), R14.2, R16.2, R17.2, R18.1
unnamed: IC1.2 (-), R13.2, R16.1
unnamed: IC1.9 (-), R10.1, R11.2
unnamed: IC1.13 (-), R12.1, R14.1, R15.2, R17.1
unnamed: J2.P3 (3), R1.1
unnamed: J3.P3 (3), R3.1
unnamed: J4.P3 (3), R2.1
SignInB: J13.1, R9.2, R10.2, R12.2
SignInT: J1.P3 (3), J16.1

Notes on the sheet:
Émilie Gillet
HW/FW rectifiers
rewrite by karl.stamm@gmail.com to KiCad, for 0805 two-board stack hand-craftable karltron.com and github.com/kstammits 2021-november-13
cc-by-sa

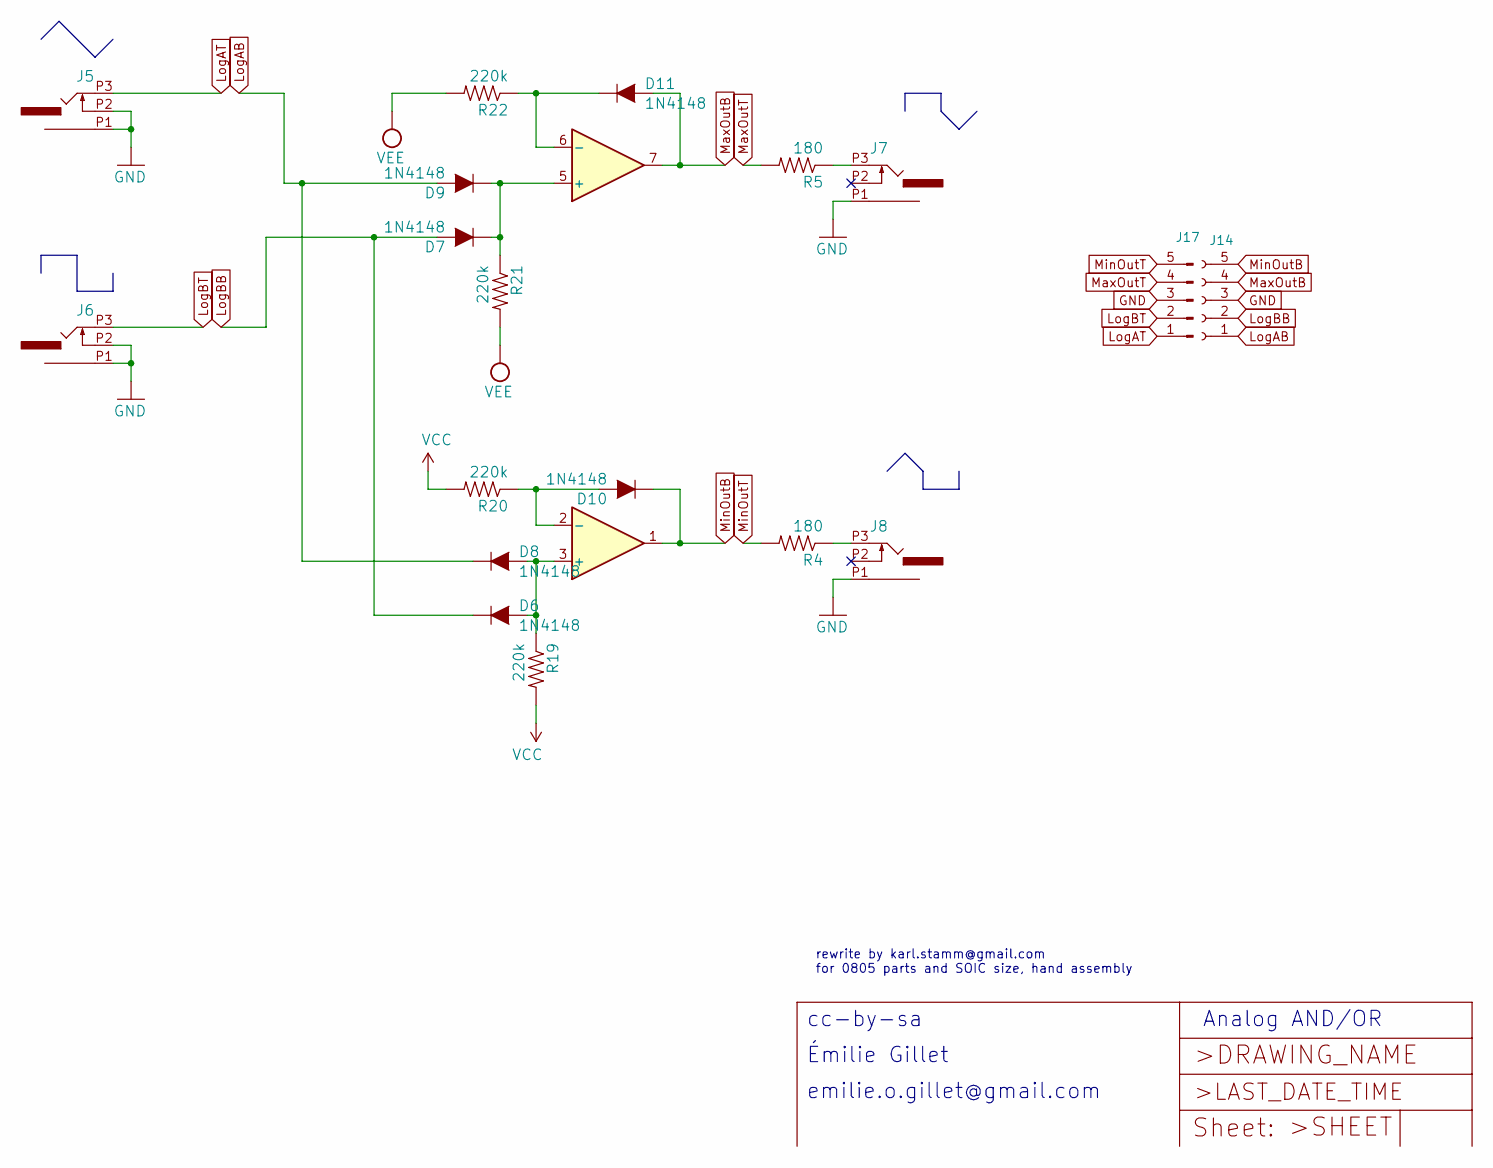
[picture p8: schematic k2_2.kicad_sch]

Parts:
D6, D7, D8, D9, D10, D11: 1N4148; D_1206_3216Metric_Pad1.42x1.75mm_HandSolder
IC2: TL072; SOIC-8_3.9x4.9mm_P1.27mm
J5, J6, J7, J8: PJ301_THONKICONN6; WQP_PJ_301M6
J14: Conn_01x05_Female; PinHeader_1x05_P2.54mm_Vertical
J17: Conn_01x05_Male; PinHeader_1x05_P2.54mm_Vertical
R4, R5: 180; R_0805_2012Metric_Pad1.20x1.40mm_HandSolder
R19, R20, R21, R22: 220k; R_0805_2012Metric_Pad1.20x1.40mm_HandSolder

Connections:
GND: J5.P1 (1), J5.P2 (2), J6.P1 (1), J6.P2 (2), J7.P1 (1), J8.P1 (1), J14.3, J17.3; also elsewhere on the board
LogAB: D8.1 (K), D9.2 (A), J14.1
LogAT: J5.P3 (3), J17.1
LogBB: D6.1 (K), D7.2 (A), J14.2
LogBT: J6.P3 (3), J17.2
MaxOutB: D11.2 (A), IC2.7, J14.4
MaxOutT: J17.4, R5.2
MinOutB: D10.1 (K), IC2.1, J14.5
MinOutT: J17.5, R4.2
unnamed: D6.2 (A), D8.2 (A), IC2.3 (+), R19.1
unnamed: D7.1 (K), D9.1 (K), IC2.5 (+), R21.1
unnamed: D10.2 (A), IC2.2 (-), R20.1
unnamed: D11.1 (K), IC2.6 (-), R22.1
unnamed: J7.P3 (3), R5.1
unnamed: J8.P3 (3), R4.1
VCC: R19.2, R20.2; also elsewhere on the board
VEE: R21.2, R22.2; also elsewhere on the board

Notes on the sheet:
emilie.o.gillet@gmail.com
cc-by-sa
Émilie Gillet
rewrite by karl.stamm@gmail.com for 0805 parts and SOIC size, hand assembly
Analog AND/OR

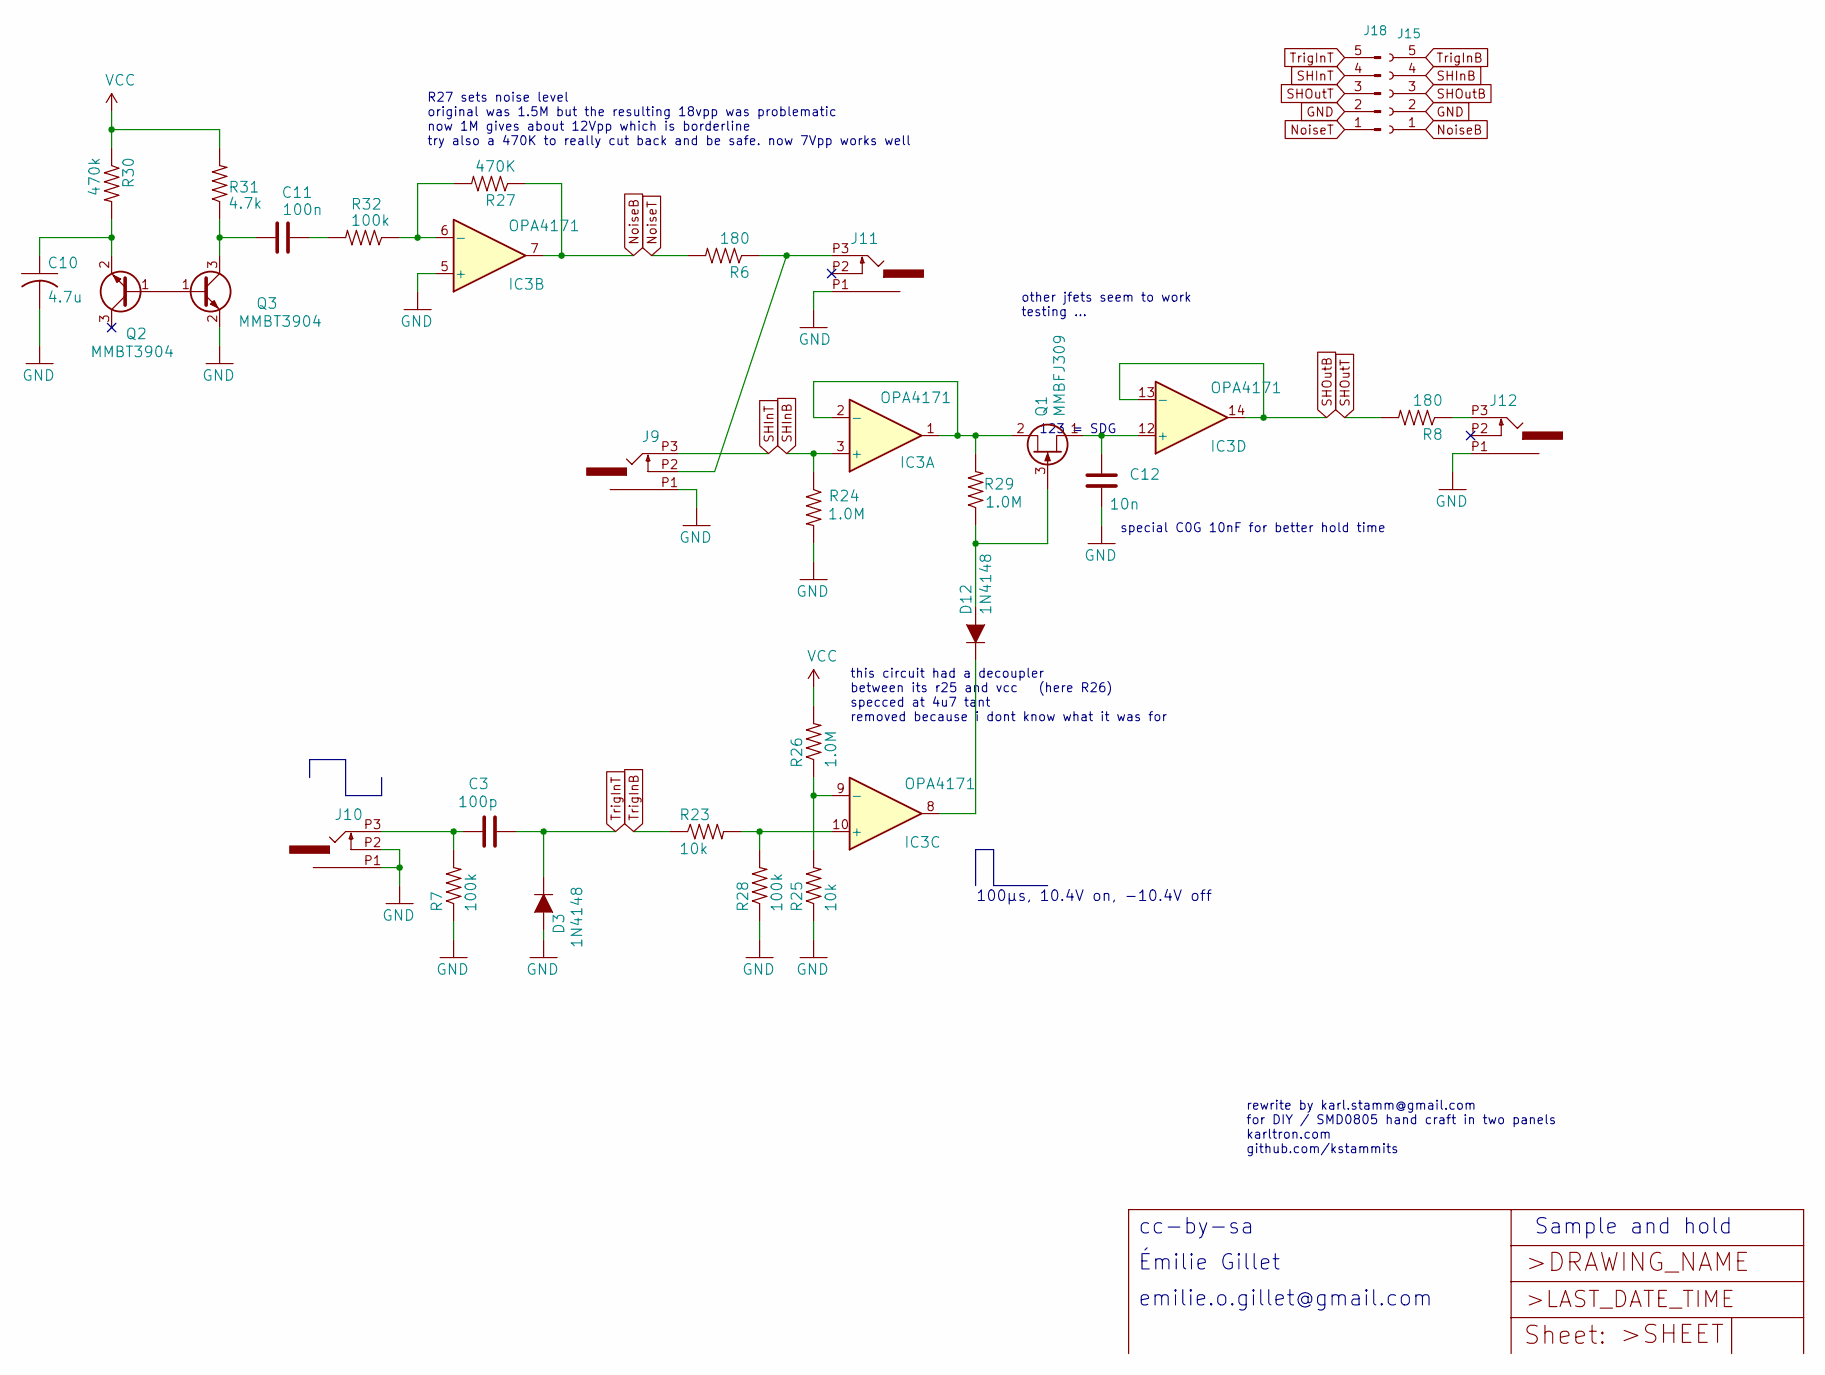
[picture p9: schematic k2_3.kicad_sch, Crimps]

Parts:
C3: 100p; C_0805_2012Metric_Pad1.18x1.45mm_HandSolder
C10: 4.7u; C_0805_2012Metric_Pad1.18x1.45mm_HandSolder
C11: 100n; C_0805_2012Metric_Pad1.18x1.45mm_HandSolder
C12: 10n; C_0805_2012Metric_Pad1.18x1.45mm_HandSolder
D3, D12: 1N4148; D_1206_3216Metric_Pad1.42x1.75mm_HandSolder
IC3: OPA4171; SOIC-14_3.9x8.7mm_P1.27mm
J9, J10, J11, J12: PJ301_THONKICONN6; WQP_PJ_301M6
J15: Conn_01x05_Female; PinHeader_1x05_P2.54mm_Vertical
J18: Conn_01x05_Male; PinHeader_1x05_P2.54mm_Vertical
Q1: MMBFJ309; SOT-23_Handsoldering
Q2, Q3: MMBT3904; SOT-23_Handsoldering
R6, R8: 180; R_0805_2012Metric_Pad1.20x1.40mm_HandSolder
R7, R28, R32: 100k; R_0805_2012Metric_Pad1.20x1.40mm_HandSolder
R23, R25: 10k; R_0805_2012Metric_Pad1.20x1.40mm_HandSolder
R24, R26, R29: 1.0M; R_0805_2012Metric_Pad1.20x1.40mm_HandSolder
R27: 470K; R_0805_2012Metric_Pad1.20x1.40mm_HandSolder
R30: 470k; R_0805_2012Metric_Pad1.20x1.40mm_HandSolder
R31: 4.7k; R_0805_2012Metric_Pad1.20x1.40mm_HandSolder

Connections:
GND: C10.2, C12.2, D3.2 (A), IC3.5 (+), J9.P1 (1), J10.P1 (1), J10.P2 (2), J11.P1 (1), J12.P1 (1), J15.2, J18.2, Q3.2 (E), R7.1, R24.2, R25.1, R28.1; also elsewhere on the board
unnamed: C11.2, R32.2
unnamed: D12.2 (A), Q1.3 (G), R29.1
unnamed: D12.1 (K), IC3.8
unnamed: IC3.1, IC3.2 (-), Q1.2 (D), R29.2
unnamed: IC3.6 (-), R27.2, R32.1
unnamed: IC3.10 (+), R23.2, R28.2
unnamed: IC3.9 (-), R25.2, R26.1
unnamed: C12.1, IC3.12 (+), Q1.1 (S)
unnamed: C3.1, J10.P3 (3), R7.2
unnamed: J9.P2 (2), J11.P3 (3), R6.1
unnamed: J12.P3 (3), R8.1
unnamed: Q2.1 (B), Q3.1 (B)
unnamed: C10.1, Q2.2 (E), R30.2
unnamed: C11.1, Q3.3 (C), R31.1
NoiseB: IC3.7, J15.1, R27.1
NoiseT: J18.1, R6.2
SHInB: IC3.3 (+), J15.4, R24.1
SHInT: J9.P3 (3), J18.4
SHOutB: IC3.13 (-), IC3.14, J15.3
SHOutT: J18.3, R8.2
TrigInB: J15.5, R23.1
TrigInT: C3.2, D3.1 (K), J18.5
VCC: R26.2, R30.1, R31.2; also elsewhere on the board

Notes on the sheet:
special C0G 10nF for better hold time
rewrite by karl.stamm@gmail.com for DIY / SMD0805 hand craft in two panels karltron.com github.com/kstammits
cc-by-sa
100µs, 10.4V on, -10.4V off
this circuit had a decoupler between its r25 and vcc (here R26) specced at 4u7 tant removed because i dont know what it was for
Émilie Gillet
123 = SDG
emilie.o.gillet@gmail.com
R27 sets noise level original was 1.5M but the resulting 18vpp was problematic now 1M gives about 12Vpp which is borderline try also a 470K to really cut back and be safe. now 7Vpp works well
Sample and hold
other jfets seem to work testing ...

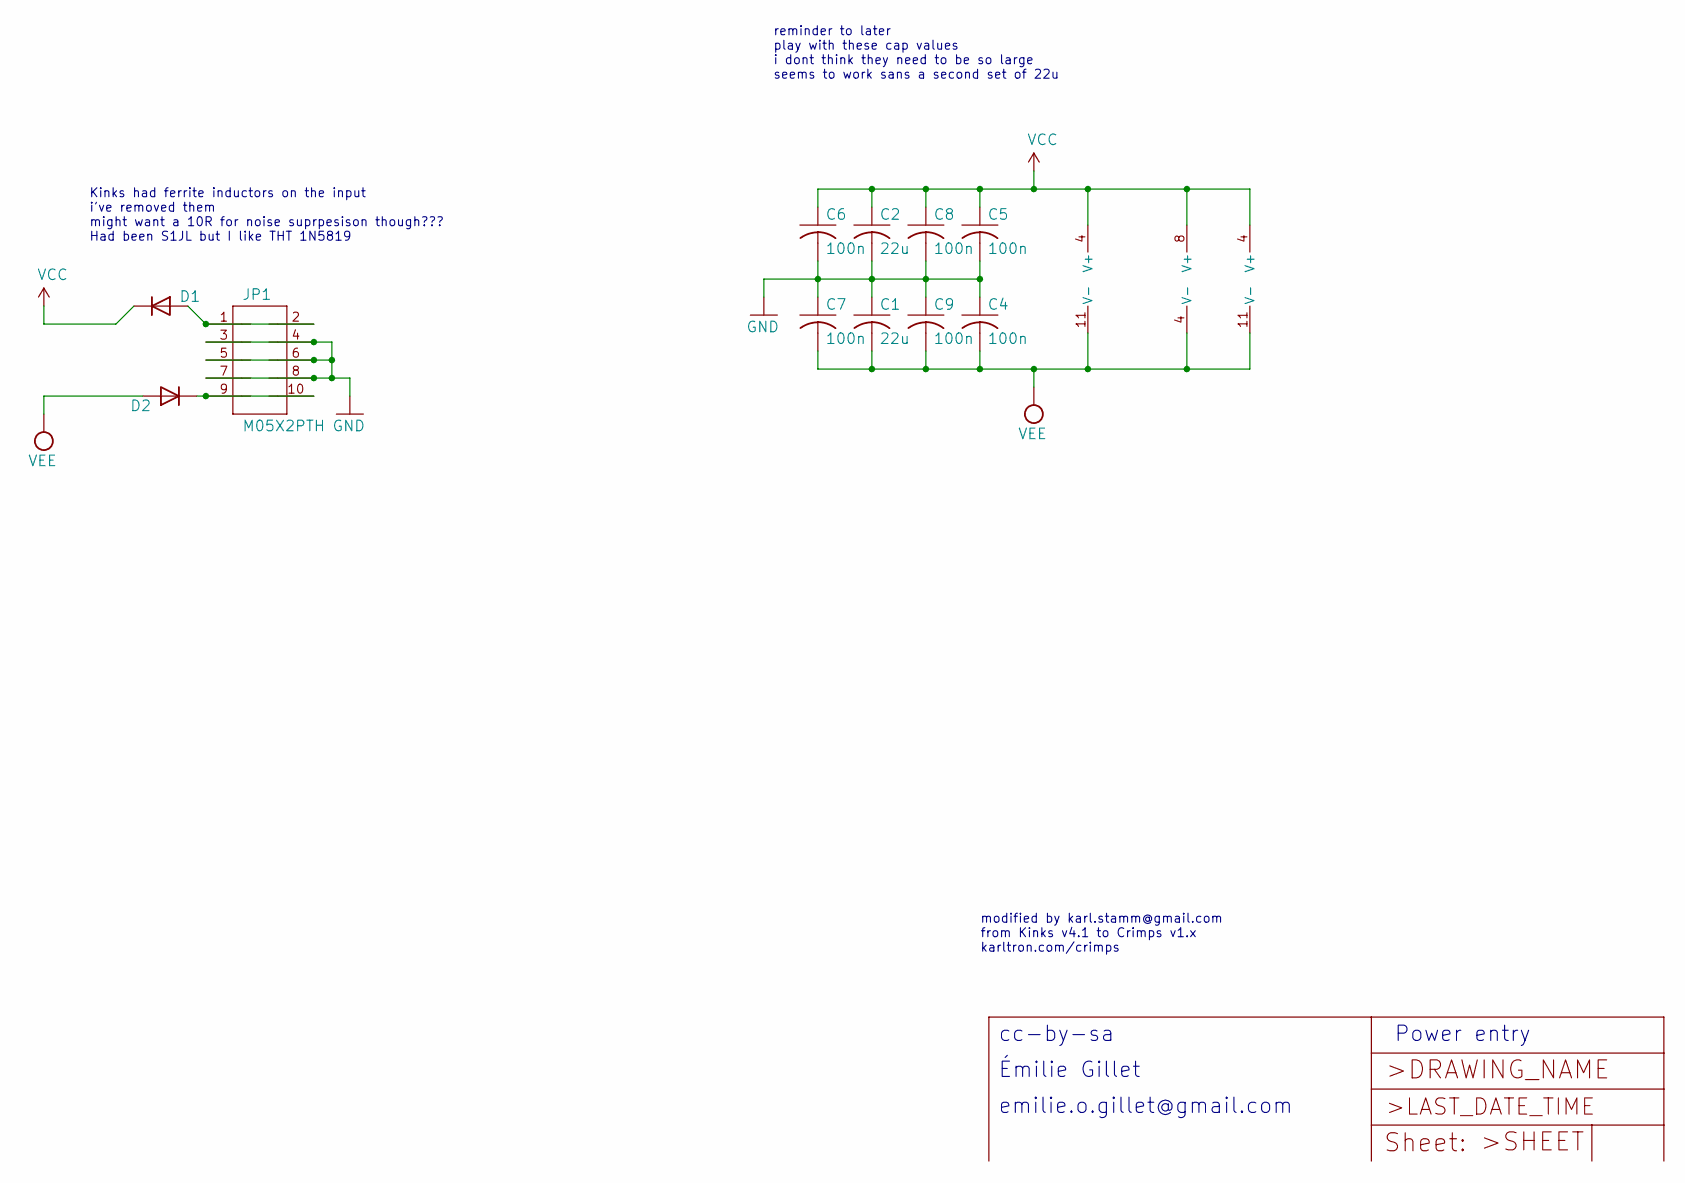
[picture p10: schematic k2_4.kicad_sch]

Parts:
C1, C2: 22u; CP_Radial_D6.3mm_P2.50mm
C4, C5, C6, C7, C8, C9: 100n; C_0805_2012Metric_Pad1.18x1.45mm_HandSolder
D1, D2: S1JL; D_DO-41_SOD81_P10.16mm_Horizontal
IC1: TL074; SOIC-14_3.9x8.7mm_P1.27mm
IC2: TL072; SOIC-8_3.9x4.9mm_P1.27mm
IC3: OPA4171; SOIC-14_3.9x8.7mm_P1.27mm
JP1: M05X2PTH; AVR_ICSP

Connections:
GND: C1.1, C2.2, C4.1, C5.2, C6.2, C7.1, C8.2, C9.1, JP1.3, JP1.4, JP1.5, JP1.6, JP1.7, JP1.8; also elsewhere on the board
unnamed: D1.2 (A), JP1.1, JP1.2
unnamed: D2.1 (K), JP1.9, JP1.10
VCC: C2.1, C5.1, C6.1, C8.1, D1.1 (K), IC1.4 (V+), IC2.8 (V+), IC3.4 (V+); also elsewhere on the board
VEE: C1.2, C4.2, C7.2, C9.2, D2.2 (A), IC1.11 (V-), IC2.4 (V-), IC3.11 (V-); also elsewhere on the board

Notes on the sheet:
Émilie Gillet
Kinks had ferrite inductors on the input i've removed them might want a 10R for noise suprpesison though??? Had been S1JL but I like THT 1N5819
Power entry
cc-by-sa
reminder to later play with these cap values i dont think they need to be so large seems to work sans a second set of 22u
modified by karl.stamm@gmail.com from Kinks v4.1 to Crimps v1.x karltron.com/crimps
emilie.o.gillet@gmail.com

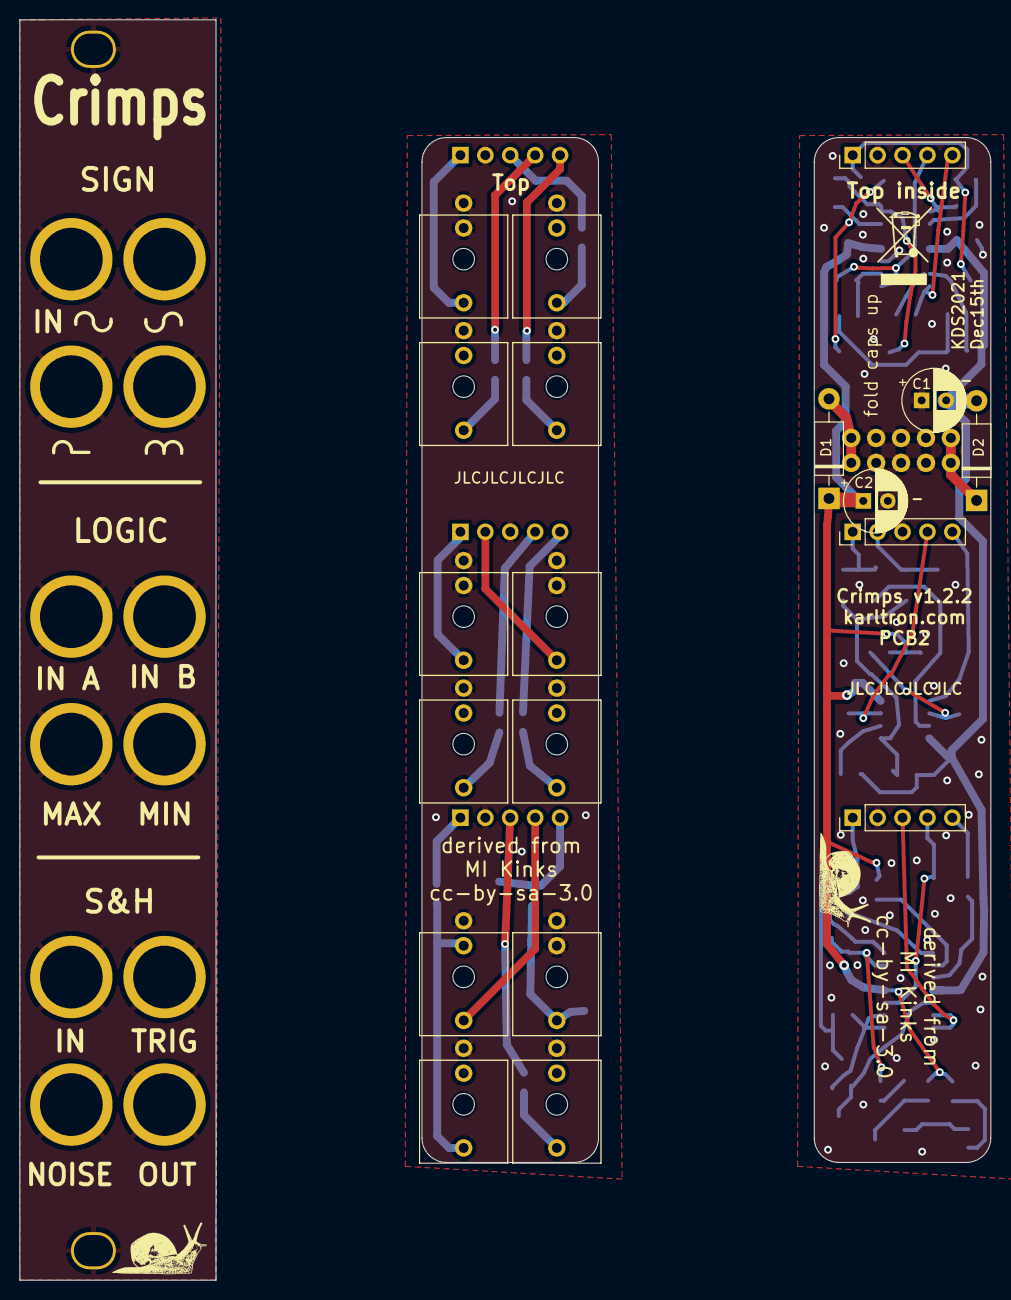
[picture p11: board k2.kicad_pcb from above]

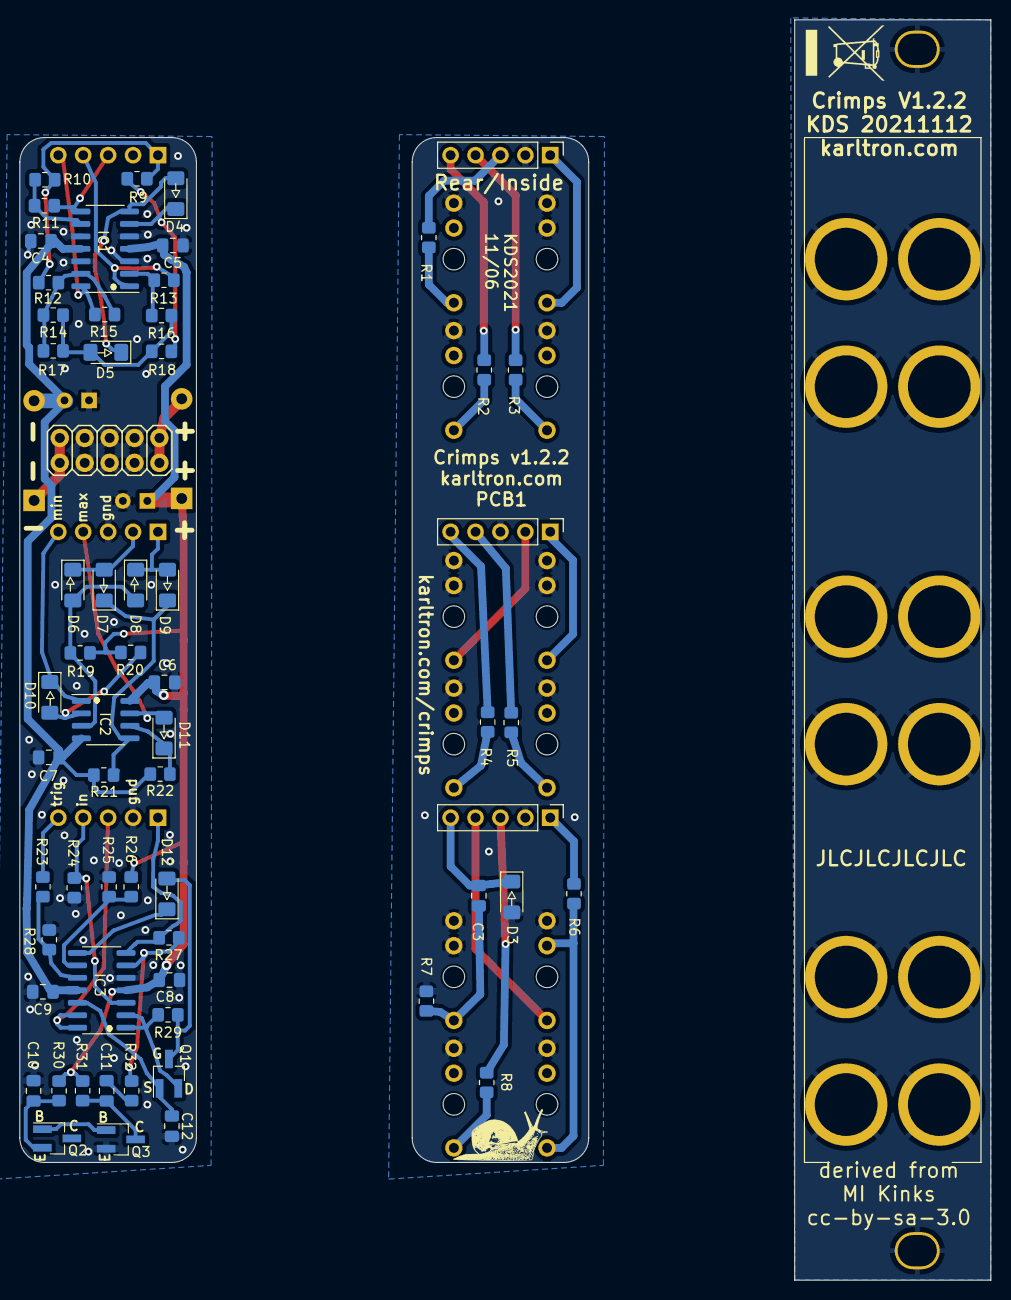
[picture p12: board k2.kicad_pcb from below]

Board: 2 copper layers, 99.0 x 128.5 mm, 96 parts (62 on the bottom side), 58 nets.

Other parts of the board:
G1: Logo_Open_Hardware_Small; snail4.sm
H1, H14: MountingHole_Pad; SLOT-1
H2, H2#2, H2#3, H2#4, H2#5, H2#6, H2#7, H2#8, H2#9: J1; MountingHole_6.4mm_M6_Pad
H6, H6#2, H6#3: J2; MountingHole_6.4mm_M6_Pad

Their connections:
GND: H1.1, H2.1, H2#2.1, H2#3.1, H2#4.1, H2#5.1, H2#6.1, H2#7.1, H2#8.1, H2#9.1, H6.1, H6#2.1, H6#3.1, H14.1; also elsewhere on the board

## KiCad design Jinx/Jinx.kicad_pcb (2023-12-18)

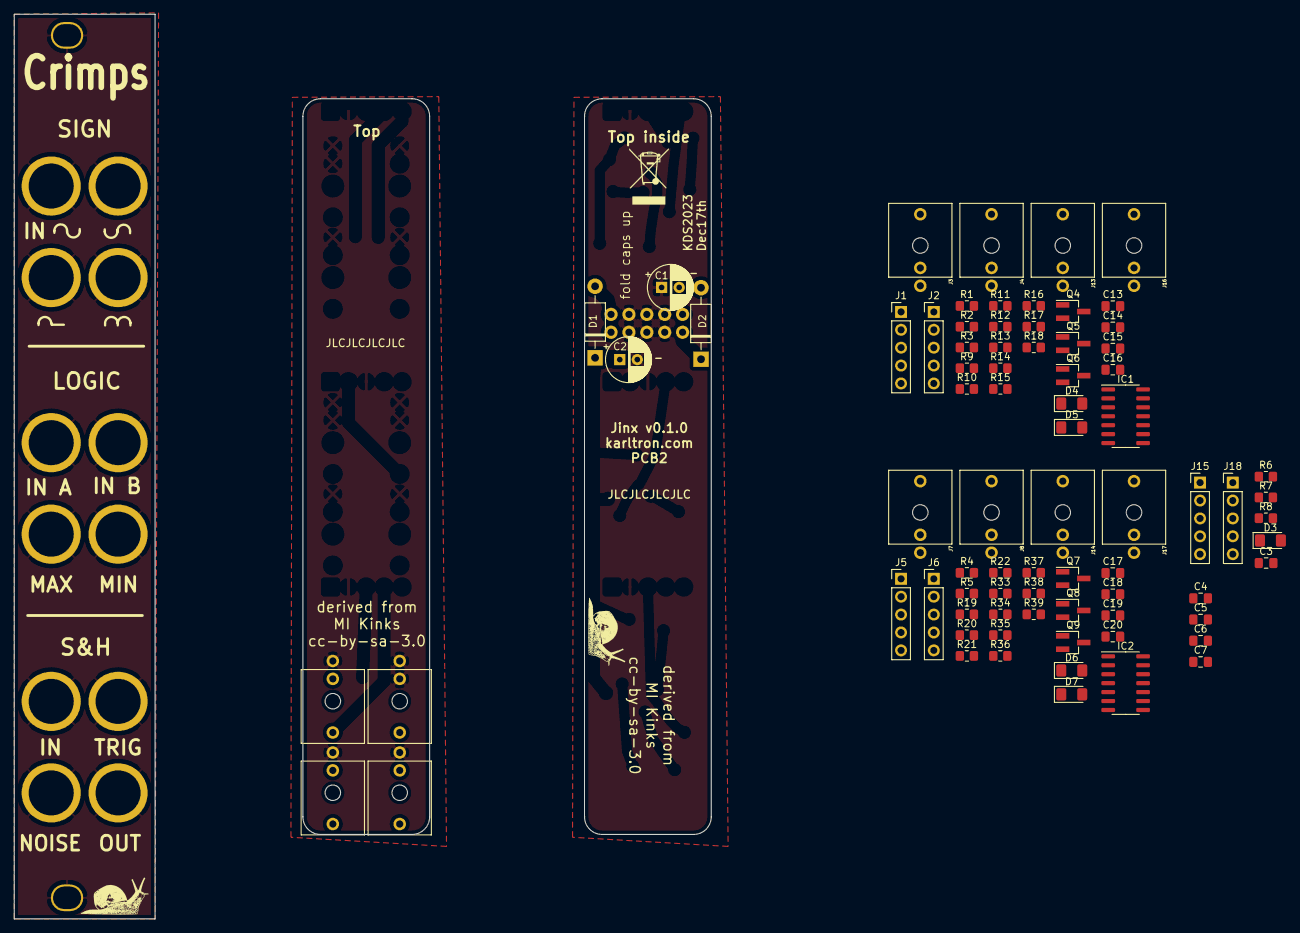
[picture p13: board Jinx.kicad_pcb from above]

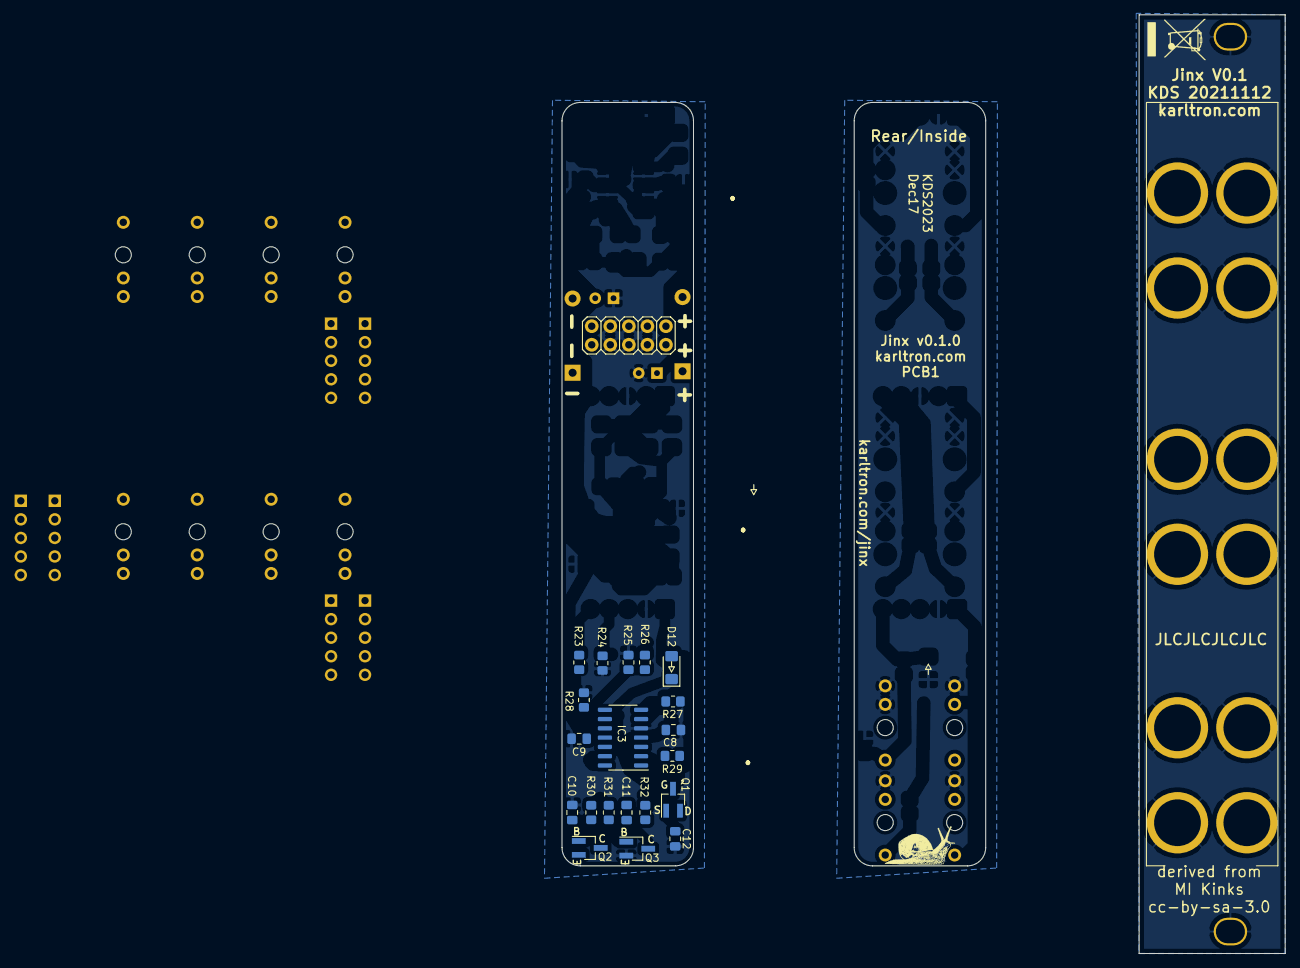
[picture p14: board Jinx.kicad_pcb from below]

Board: 2 copper layers, 113 parts (21 on the bottom side), 55 nets, no tracks yet.

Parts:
C1, C2: 22u; CP_Radial_D6.3mm_P2.50mm
C3, C16, C20: 100p; C_0805_2012Metric_Pad1.18x1.45mm_HandSolder
C4, C5, C6, C7, C8, C9, C11, C13, C17: 100n; C_0805_2012Metric_Pad1.18x1.45mm_HandSolder
C10, C14, C18: 4.7u; C_0805_2012Metric_Pad1.18x1.45mm_HandSolder
C12, C15, C19: 10n; C_0805_2012Metric_Pad1.18x1.45mm_HandSolder
D1, D2: S1JL; D_DO-41_SOD81_P10.16mm_Horizontal
D3, D4, D5, D6, D7, D12: 1N4148; D_1206_3216Metric_Pad1.42x1.75mm_HandSolder
G1: Logo_Open_Hardware_Small; snail4.sm
H1, H14: MountingHole_Pad; SLOT-1
H2, H2#2, H2#3, H2#4, H2#5, H2#6, H2#7, H2#8, H2#9: J1; MountingHole_6.4mm_M6_Pad
H6, H6#2, H6#3: J2; MountingHole_6.4mm_M6_Pad
IC1, IC2, IC3: TL074; SOIC-14_3.9x8.7mm_P1.27mm
J1, J5, J18: Conn_01x05_Male; PinHeader_1x05_P2.54mm_Vertical
J2, J6, J15: Conn_01x05_Female; PinHeader_1x05_P2.54mm_Vertical
J3, J4, J7, J8, J9, J10, J11, J12, J13, J14, J16, J17: PJ301_THONKICONN6; WQP_PJ_301M6
JP1: M05X2PTH; AVR_ICSP
Q1, Q6, Q9: MMBFJ309; SOT-23_Handsoldering
Q2, Q3, Q4, Q5, Q7, Q8: MMBT3904; SOT-23_Handsoldering
R1, R4, R30: 470k; R_0805_2012Metric_Pad1.20x1.40mm_HandSolder
R2, R5, R31: 4.7k; R_0805_2012Metric_Pad1.20x1.40mm_HandSolder
R3, R19, R27: 470K; R_0805_2012Metric_Pad1.20x1.40mm_HandSolder
R6, R8, R10, R11, R21, R22: 180; R_0805_2012Metric_Pad1.20x1.40mm_HandSolder
R7, R9, R16, R17, R20, R28, R32, R37, R38: 100k; R_0805_2012Metric_Pad1.20x1.40mm_HandSolder
R12, R13, R14, R24, R26, R29, R33, R34, R35: 1.0M; R_0805_2012Metric_Pad1.20x1.40mm_HandSolder
R15, R18, R23, R25, R36, R39: 10k; R_0805_2012Metric_Pad1.20x1.40mm_HandSolder

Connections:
GND: C1.1, C2.2, C4.1, C5.2, C6.2, C7.1, C8.2, C9.1, C10.2, C12.2, C14.2, C15.2, C18.2, C19.2, D3.2 (A), D5.2 (A), D7.2 (A), H1.1, H2.1, H2#2.1, H2#3.1, H2#4.1, H2#5.1, H2#6.1, H2#7.1, H2#8.1, H2#9.1, H6.1, H6#2.1, H6#3.1, H14.1, IC1.5 (+), IC2.5 (+), IC3.5 (+), J1.2, J2.2, J3.P1 (1), J4.P1 (1), J5.2, J6.2, J7.P1 (1), J8.P1 (1), J9.P1 (1), J10.P1 (1), J10.P2 (2), J11.P1 (1), J12.P1 (1), J13.P1 (1), J14.P1 (1), J15.2, J16.P1 (1), J16.P2 (2), J17.P1 (1), J17.P2 (2), J18.2, JP1.3, JP1.4, JP1.5, JP1.6, JP1.7, JP1.8, Q3.2 (E), Q5.2 (E), Q8.2 (E), R7.1, R13.2, R16.1, R17.1, R18.1, R24.2, R25.1, R28.1, R34.2, R37.1, R38.1, R39.1
unnamed: C11.2, R32.2
unnamed: C13.2, R9.2
unnamed: C17.2, R20.2
unnamed: D1.2 (A), JP1.1, JP1.2
unnamed: D2.1 (K), JP1.9, JP1.10
unnamed: D4.2 (A), Q6.3 (G), R12.1
unnamed: D4.1 (K), IC1.8
unnamed: D6.2 (A), Q9.3 (G), R33.1
unnamed: D6.1 (K), IC2.8
unnamed: D12.2 (A), Q1.3 (G), R29.1
unnamed: D12.1 (K), IC3.8
unnamed: IC1.1, IC1.2 (-), Q6.2 (D), R12.2
unnamed: IC1.6 (-), R3.2, R9.1
unnamed: IC1.10 (+), R15.2, R17.2
unnamed: IC1.9 (-), R14.1, R18.2
unnamed: C15.1, IC1.12 (+), Q6.1 (S)
unnamed: IC2.1, IC2.2 (-), Q9.2 (D), R33.2
unnamed: IC2.6 (-), R19.2, R20.1
unnamed: IC2.10 (+), R36.2, R38.2
unnamed: IC2.9 (-), R35.1, R39.2
unnamed: C19.1, IC2.12 (+), Q9.1 (S)
unnamed: IC3.1, IC3.2 (-), Q1.2 (D), R29.2
unnamed: IC3.6 (-), R27.2, R32.1
unnamed: IC3.10 (+), R23.2, R28.2
unnamed: IC3.9 (-), R25.2, R26.1
unnamed: C12.1, IC3.12 (+), Q1.1 (S)
unnamed: J4.P3 (3), R11.1
unnamed: J8.P3 (3), R22.1
unnamed: C3.1, J10.P3 (3), R7.2
unnamed: J9.P2 (2), J11.P3 (3), R6.1
unnamed: J12.P3 (3), R8.1
unnamed: J3.P3 (3), J13.P2 (2), R10.1
unnamed: J7.P3 (3), J14.P2 (2), R21.1
unnamed: C16.1, J16.P3 (3), R16.2
unnamed: C20.1, J17.P3 (3), R37.2
unnamed: Q2.1 (B), Q3.1 (B)
unnamed: C10.1, Q2.2 (E), R30.2
unnamed: C11.1, Q3.3 (C), R31.1
unnamed: Q4.1 (B), Q5.1 (B)
unnamed: C14.1, Q4.2 (E), R1.2
unnamed: C13.1, Q5.3 (C), R2.1
unnamed: Q7.1 (B), Q8.1 (B)
unnamed: C18.1, Q7.2 (E), R4.2
unnamed: C17.1, Q8.3 (C), R5.1
NoiseB: IC1.7, IC2.7, IC3.7, J2.1, J6.1, J15.1, R3.1, R19.1, R27.1
NoiseT: J1.1, J5.1, J18.1, R6.2, R10.2, R21.2
SHInB: IC1.3 (+), IC2.3 (+), IC3.3 (+), J2.4, J6.4, J15.4, R13.1, R24.1, R34.1
SHInT: J1.4, J5.4, J9.P3 (3), J13.P3 (3), J14.P3 (3), J18.4
SHOutB: IC1.13 (-), IC1.14, IC2.13 (-), IC2.14, IC3.13 (-), IC3.14, J2.3, J6.3, J15.3
SHOutT: J1.3, J5.3, J18.3, R8.2, R11.2, R22.2
TrigInB: J2.5, J6.5, J15.5, R15.1, R23.1, R36.1
TrigInT: C3.2, C16.2, C20.2, D3.1 (K), D5.1 (K), D7.1 (K), J1.5, J5.5, J18.5
VCC: C2.1, C5.1, C6.1, C8.1, D1.1 (K), IC1.4 (V+), IC2.4 (V+), IC3.4 (V+), R1.1, R2.2, R4.1, R5.2, R14.2, R26.2, R30.1, R31.2, R35.2
VEE: C1.2, C4.2, C7.2, C9.2, D2.2 (A), IC1.11 (V-), IC2.11 (V-), IC3.11 (V-)

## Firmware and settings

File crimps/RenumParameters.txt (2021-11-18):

PCB file name=k2
Top Sort Direction=4
Bottom Sort Direction=5
Top Start Reference Designation=1
Bottom Start Reference Designation=0
Sort on Modules/Reference Designators=1
Sort Grid=1.000000
Log=-430081576

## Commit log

2021-11-18 initial
    upload of k2, derived from eagle and rewritten fully Crimps v1.0.1. Initial board prototype!
    [RenumParameters.txt, k2.kicad_pcb, k2.sch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]
2021-11-19 v101 to order
    tweaks
    [k2.kicad_pcb]
2021-11-19 adding BOM
    [BOM.csv]
2021-11-19 Create BOM.Guide.xlsx
    nicer to read BOM
    [BOM.Guide.xlsx]
2021-12-13 dec2021
    status after testing v101
    found errors in this board
    [BOM.Guide.xlsx, k2.kicad_pcb, k2_3.sch]
2021-12-15 upd to board 1.2
    should fix transistor footprint and shift diodes
    [BOM.Guide.xlsx, k2.kicad_pcb, k2_3.sch]
2021-12-16 versioning
    nudge traces
    [k2.kicad_pcb]
2021-12-16 printing pretty schem
    [k2_1.sch, k2_3.sch, k2_4.sch]
2021-12-21 update for noise level
    [BOM.Guide.xlsx, k2_3.sch]
2022-02-01 ibom
    move files and add an ibom.html
    [BOM.Guide.xlsx, BOM.csv, k2.kicad_pcb]
2022-02-02 logo added
    adding WEEE wheelie bin
    [k2.kicad_pcb]
2023-12-18 versioning
    kicad upd tweaks
2023-12-18 Shift Files
    Sorry we have to move a lot of files to add another board
2023-12-18 adding Jinx as a subfolder
    [Jinx.kicad_pcb, Jinx.kicad_sch, Jinx.sch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]
2024-08-27 update bom and version
    [BOM.Guide.xlsx, k2.csv, k2.kicad_pcb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]

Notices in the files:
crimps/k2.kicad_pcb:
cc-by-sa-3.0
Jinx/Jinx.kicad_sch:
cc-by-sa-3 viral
